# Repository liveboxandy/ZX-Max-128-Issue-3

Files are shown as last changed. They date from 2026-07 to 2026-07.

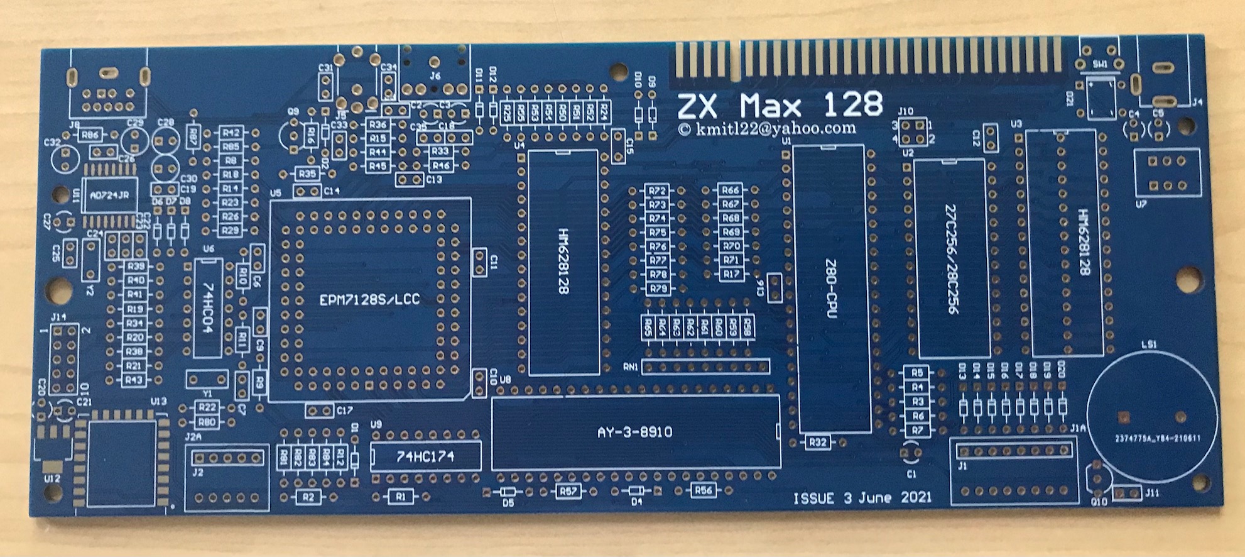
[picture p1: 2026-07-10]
ZX Max 128 Issue 3 June 2021 pcb .jpg

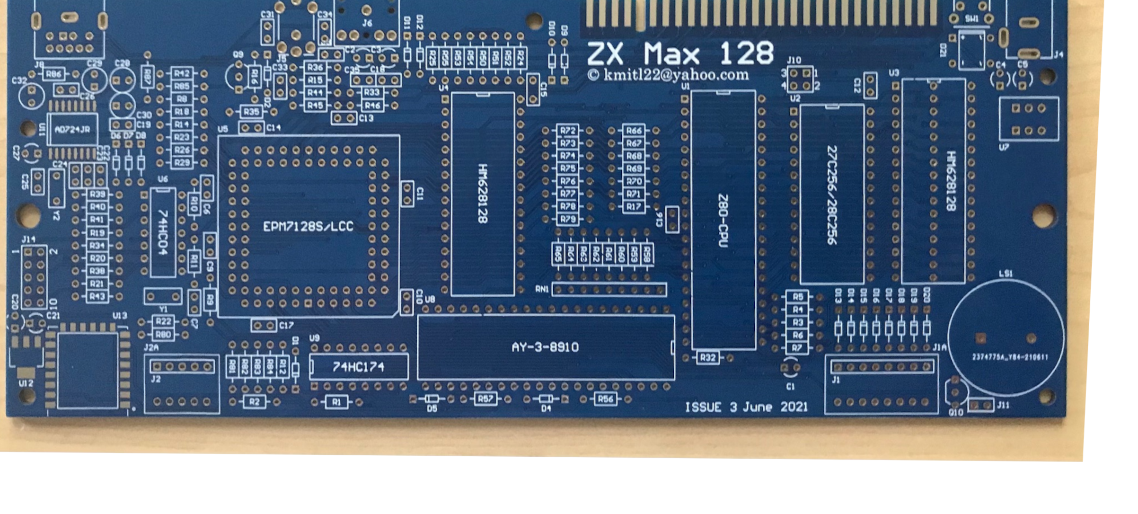
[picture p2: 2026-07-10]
Max 128 Issue 3 June 2021 pcb2.png

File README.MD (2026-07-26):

ZX Max 128 Issue 3.

This Kicad project has only been done so as to allow for a proper ibom that includes tracks and vias
to be created to make assembling easier.
A lot of work was done in order to ensure that the footprints were located as close as possible to 
those in the original as well tying to follow the existing track and via locations. Some of the
footprints that were downloaded from Digikey based on the parts in the official BOM do not fit 
exactly in their locations on the board. C15 is one example, I had to modify it's footprint to fit
the pad dimensions. Some other capacitors also do not fit correctly but appear to be close enough.

As such, although I have tried to be as accurate as possible I would NOT use these gerbers to have a
pcb manufactured without having another set of eyes checking that the schematic that I have produced
is correct to that produced by DonSuperfo and that the pcb data from Kicad reports no major errors 
with regards to copper tracing and via positions.

The KiCAD schematics 'should' be correct but nothing should be assumed as correct without checking with the original schematic and PCB layout. Although I have followed the original track and via layout further checking should be done before using these files to order a pcb with. Currently I would still order the pcb from PCBWay using the link from https://github.com/DonSuperfo/ZX-Max-128

Note that any part number for any device used in this project might not be the correct one from the original BOM as supplied from PCBWay as I had to change some parts to get a footprint that would fit in the space on the original pcb with the correct pin spacing. This required selecting a different part number or vendor. This applies mainly to capacitors. Some other parts are no longer available under that number from Digikey.

As always, measure twice and order one.

Use at your own risk.

For the jumpers/connectors on the board,

J1/J1A1 8 Way Keyboard Connector

J2/J2A1 5 Way Keyboard Connector

J3 Zx Expansion Connector

J4 DC Input can be any polarity. 

J5 Video is a TRRS, Tip-Video,RR-Left/Right, Screen-Ground.

J6 Ear/Mic. Wired as per ZX Spectrum 128K +3. TRS. Tip-Mic, Ring-Ear, Screen-Ground.

J7 Not Used

J8 SCART, mates with a Sega megadrive cable for SCART.

J9 Not Used

J10 EEPROM/EPROM selection, EEPROM 2-4/1-3, UVEPROM 2-1/4-3.

J11 Speaker On/Off

J12 Not Used

J13 Not Used

J14 JTAG for the EPM7128 wired as standard to an Altera device.

J15 Not Used

J16 Disable DivMMC, close = enable DivMMC, open = disable DivMMC or need to update program on U17

SW1 RESET

From information on the original website,

In order to make ACB output more balanced I would recommend following the -4.5 dB panning law rule and make these updates:

R54, R55 = 470 Ohm
R51, R52 = 560 Ohm
R50, R53 = 330 Ohm

The ratio of 560 / 330 = 1.6969 is a close approximation of 1 / 10^(-4.5 / 20) = 1.6788. 
Also the resulting equivalent resistance is around 1000 Ohm which leads to less distortion on AY outputs.

mismatch between the value on the scheme and in the BOM for part R32 (INT)
on scheme it is 470R but in BOM 10k.
it looks like in BOM incorrect value.

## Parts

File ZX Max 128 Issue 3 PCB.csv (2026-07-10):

Source: | E:\Kicad\ZX Max 128 Issue 3\ZX Max 128 Issue 3 PCB.kicad_sch
Date: | 2026-07-10T22:37:54
Tool: | Eeschema 10.0.4
Generator: | C:\Program Files\KiCad\7.0\bin\scripting\plugins/bom_csv_grouped_by_value_with_fp.py
Component Count: | 164
Ref | Qnty | Value | Cmp name | Footprint | Description | Vendor | DNP
C1, C2, C3, C4, C20, C21, C27 | 7 | 10uF 25V | ECA-1EM100B | Mod:CAPPRD200W50D500H1100 | ECA-1EM100B - 10uF Aluminum Electrolytic Capacitors Radial
C5 | 1 | 22uF 16V | ECA-1EM100B | Mod:CAPPRD200W50D500H1100 | ECA-1EM100B - 10uF Aluminum Electrolytic Capacitors Radial
C6, C7 | 2 | 27pF | FG18C0G1H270JNT06 | Mod:CAPRB250W50L400T250H550
C8, C9, C10, C11, C12, C13, C14, C16, C17, C18, C22, C23, C24, C26, C31, C34 | 16 | 100nF | K104Z15Y5VF5TL2 | Mod:CAPRB250W50L400T250H550 | Vishay K 100nF Ceramic Multilayer Capacitor, 100 V dc, +85C, Y5V Dielectric, +80 %, -20 %
C15 | 1 | 100nF | K104Z15Y5VF5TL2 | Mod:Capacitor 3.8mm PItch | Vishay K 100nF Ceramic Multilayer Capacitor, 100 V dc, +85C, Y5V Dielectric, +80 %, -20 %
C19, C35 | 2 | 3n3 50V | K104Z15Y5VF5TL2 | Mod:CAPRB250W50L400T250H550 | Vishay K 100nF Ceramic Multilayer Capacitor, 100 V dc, +85C, Y5V Dielectric, +80 %, -20 %
C25 | 1 | 10pF | K104Z15Y5VF5TL2 | Mod:CAPRB250W50L400T250H550 | Vishay K 100nF Ceramic Multilayer Capacitor, 100 V dc, +85C, Y5V Dielectric, +80 %, -20 %
C28, C29, C30, C32 | 4 | 220uF 16V | 16YXJ220MT16.3X11 | Mod:CAP_YX_6P3X11_RUB
C33 | 1 | 10nF 50V | K104Z15Y5VF5TL2 | Mod:CAPRB250W50L400T250H550 | Vishay K 100nF Ceramic Multilayer Capacitor, 100 V dc, +85C, Y5V Dielectric, +80 %, -20 %
D1, D2, D4, D5, D6, D7, D8, D9, D10, D11, D12, D13, D14, D15, D16, D17, D18, D19, D20 | 19 | 1N4148 | 1N4148 | Mod:DIOAD753W49L380D172B | Diode 1N4148
D21 | 1 | DF02M | DF02M | Mod:DIP825W58P510L832H543Q4N | Bridge Rectifier DF02M 1A
J1 | 1 | 8 Pin FFC | 5-520315-8 | Mod:55203155 | Connector FFC Socket 8 Pin
J1A1 | 1 | 8 Pin JST XH | B8B-XH-A_LF__SN_ | Mod:JST_B8B-XH-A_LF__SN_ | Connector Header Through Hole 8 position 0.098 (2.50mm)
J2 | 1 | 5 Pin FFC | 5-520315-5 | Mod:55203155 | Connector FFC Socket 5 Pin
J2A1 | 1 | 5 Pin JST XH | B5B-XH-A_LF__SN_ | Mod:JST_B5B-XH-A_LF__SN_ | Connector Header Through Hole 5 position 0.098 (2.50mm)
J3 | 1 | ZX_48K_EDGE | ZX_48K_EDGE | Mod:ZX_BUS_B_TOP | ZX Spectrum 48K Edge Connector
J4 | 1 | PJ-002A | PJ-002A | Mod:CUI_PJ-002A
J5 | 1 | AV Jack | AudioJack3 | Mod:PJ-322A | AV Jack PJ-322
J6 | 1 | Connector Audio 3525N | SJ1-3525N | Mod:CUI_SJ1-3525N | Connector Audio 3525N
J8 | 1 | Connector 9 Pin Mini DIN | KMDGX-9S-BS-1 | Mod:KMDGX9SBS1 | Connector 9 Pin MiniDin
J10 | 1 | Conn_02x02_Odd_Even | Conn_02x02_Odd_Even | Connector_PinHeader_2.54mm:PinHeader_2x02_P2.54mm_Vertical | Generic connector, double row, 02x02, odd/even pin numbering scheme (row 1 odd numbers, row 2 even numbers), script generated (kicad-library-utils/schlib/autogen/connector/)
J11 | 1 | CON2 | M20-9990246 | Mod:HARWIN_M20-9990246 | Header 2x1
J14 | 1 | Header 5x2 | 10129381-910002BLF | Mod:AMPHENOL_10129381-910002BLF | Header 5x2
LS1 | 1 | Speaker | Speaker | Mod:Speaker | Speaker
Q9, Q10 | 2 | Transistor BC548 | BC548BTA | Mod:BC548BTA
R1, R2, R7, R9, R12, R32, R36, R56, R57, R58, R59, R60, R61, R62, R63, R64, R65, R66, R67, R68, R69, R70, R71, R72, R73, R74, R75, R76, R77, R78, R79 | 31 | 470R | CF14JT470R | Mod:STA_CF14_STP | 470R
R3, R4, R5, R6, R15, R16, R24, R25, R35, R45, R80, R81, R82, R83, R84 | 15 | 10K0 | CF14JT10K0 | Mod:STA_CF14_STP | Resistor 10K0
R8 | 1 | 2K70 | CF14JT2K70 | Mod:STA_CF14_STP | 2K70
R10 | 1 | 1M00 | CF14JT1M00 | Mod:STA_CF14_STP | 1M00
R11, R50, R53, R54, R55 | 5 | 1K00 | CF14JT1K00 | Mod:STA_CF14_STP | 1K00
R14, R18, R23, R26, R29 | 5 | 68R0 | CF14JT68R0 | Mod:STA_CF14_STP | 68R0
R17, R22 | 2 | 4K7 | CF14JT4K70 | Mod:STA_CF14_STP | 4K70
R19, R20, R21, R34, R38, R43 | 6 | 150R | CF14JT150R | Mod:STA_CF14_STP | 150R
R33 | 1 | 33K0 | CF14JT33K0 | Mod:STA_CF14_STP | 33K0
R39, R40, R41, R42, R86, R87 | 6 | 75R0 | CF14JT75R0 | Mod:STA_CF14_STP | 75R0
R44, R46 | 2 | 150K | CF14JT150K | Mod:STA_CF14_STP | 150K
R51, R52 | 2 | 2K20 | CF14JT2K20 | Mod:STA_CF14_STP | 2K20
R85 | 1 | 470K | CF14JT470K | Mod:STA_CF14_STP | 470K
RN1 | 1 | 10K | 4609X-101-103LF | Mod:SIP249W50P254L2281H508Q9
SW1 | 1 | Switch 6x6 RA | 2-1825027-0 | Mod:SW2_1825027-G_TEC
U1 | 1 | Z80 | Z84C0010PEG | Mod:Z80_Socket | Z80 CPU
U2 | 1 | EEPROM/EPROM 32Kx8 | AT27C256R-45PU | Mod:DIP1556W56P254L3702H483Q28N | EEPROM/EPROM 32Kx8
U3 | 1 | AS6C1008-55PCN | AS6C1008-55PCN | Mod:U3
U4 | 1 | AS6C1008-55PCN | AS6C1008-55PCN | Mod:PDIP-32_MIL600_ALL
U5 | 1 | EPM7128SLC | PLCC-84-AT | Mod:PLCC84AT | EPM7128SLC-84 PLCC Socket
U6 | 1 | 74HC04 | 74HC04_1 | Mod:DIP794W53P254L1930H508Q14N | Hex Inverter
U7 | 1 | R-78E5.0-1.0 | R-78E5.0-1.0 | Mod:CONV_R-78E5.0-1.0
U8 | 1 | AY-3-8910 | AY-3-8910 | Mod:Z80_Socket
U9 | 1 | SN74HC174N | SN74HC174N | Mod:DIP794W53P254L1930H508Q16N | Hex D flip-flop w/reset,SN74HC174N DIP16
U11 | 1 | AD724JRZ | AD724JRZ | Mod:RW_16_ADI | RGB - PAL Encoder
U12 | 1 | 3V3 1Amp | AZ1117IH-3.3TRG1 | Mod:SOT230P700X185-4N | Voltage Regulator 3V3 1Amp
U15 | 1 | ESP8266-12E | ESP8266-12E | Mod:WIFI_Module_ESP8266_12E | ESP8266-12E Bluetooth Module
Y1 | 1 | 28.375Mhz | Crystal | Mod:Crystal_HC49-4H_Vertical | Two pin crystal
Y2 | 1 | 4.433Mhz | Crystal | Mod:Crystal_HC49-4H_Vertical | Two pin crystal

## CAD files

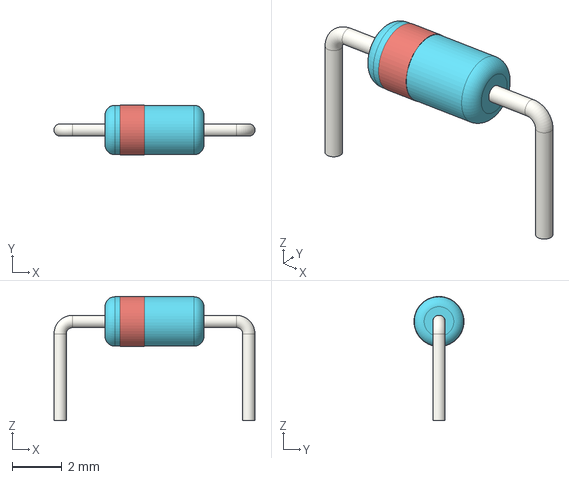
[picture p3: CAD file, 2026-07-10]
Step/D_DO-35_SOD27_P7.62mm_Horizontal.step
8.12 x 2.02 x 5.01 mm

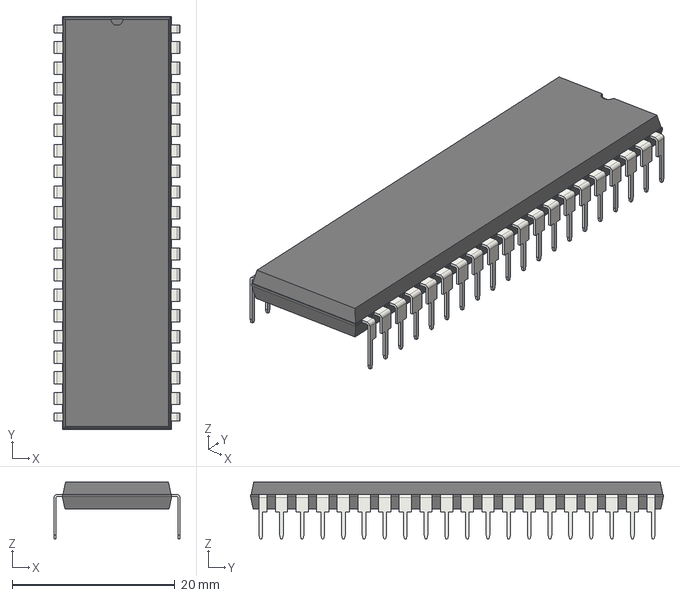
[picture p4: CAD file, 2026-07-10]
Step/DIP-40_W15.24mm.step
15.5 x 50.8 x 6.98 mm

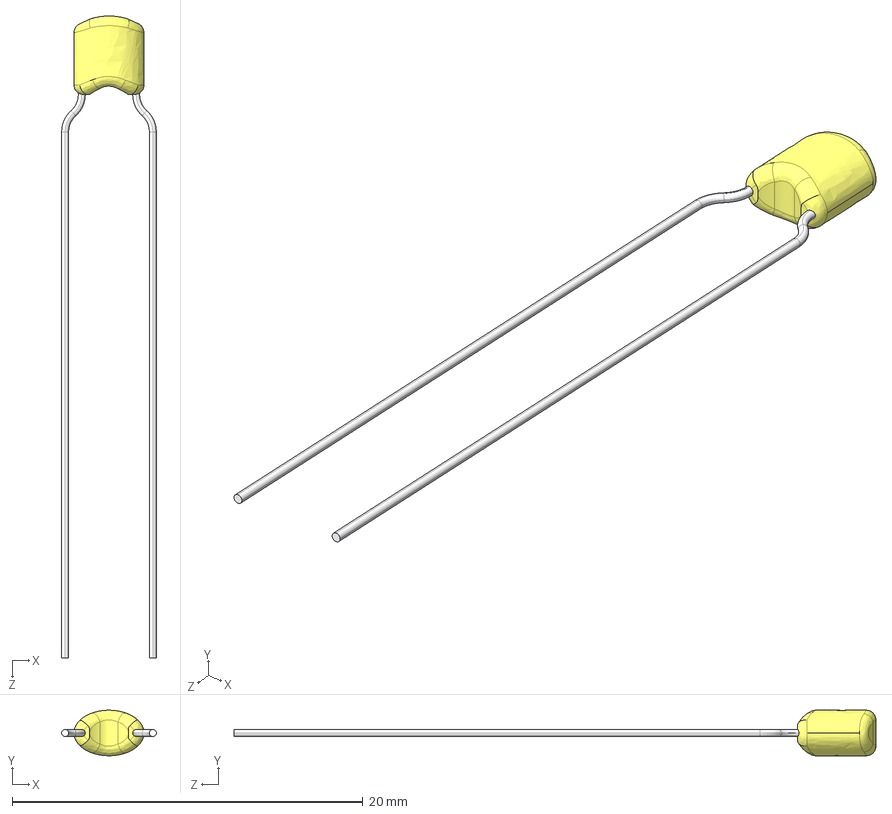
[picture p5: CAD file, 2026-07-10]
Step/Capacitor 100nF 50V MLCC K104Z15Y5VF5TL2.stp
5.40 x 2.60 x 36.6 mm

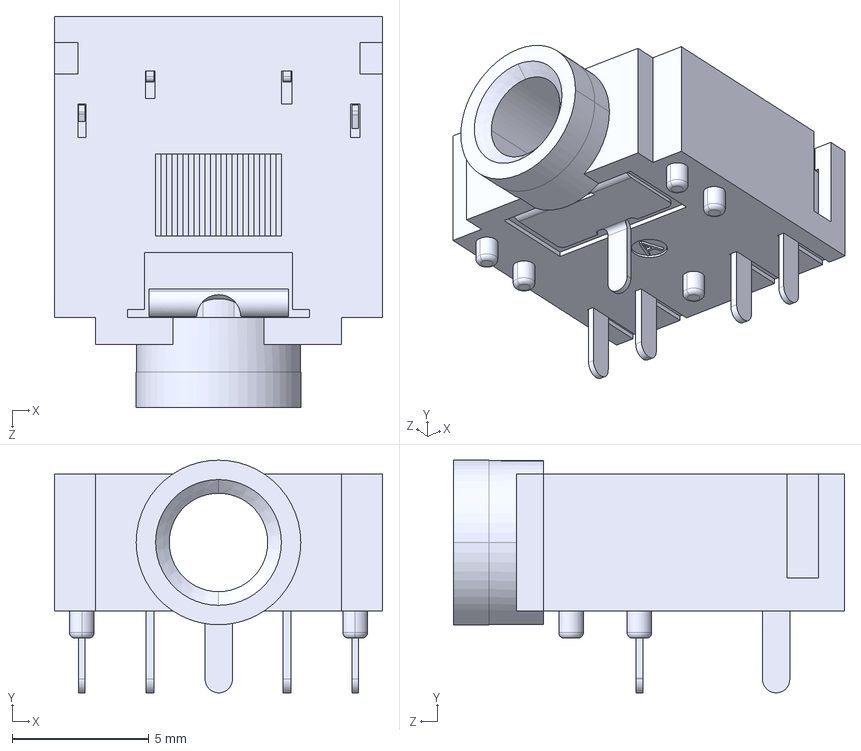
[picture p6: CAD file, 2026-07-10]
Step/Audio Connector SJ1-3525N.step
12.0 x 8.51 x 14.3 mm

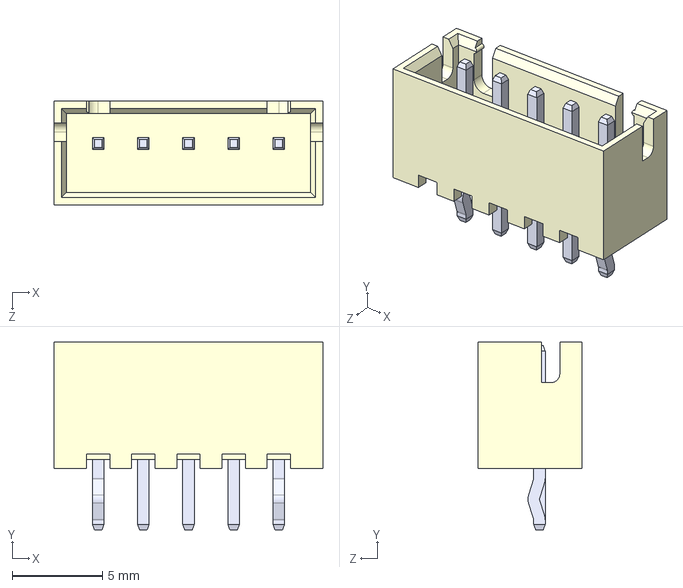
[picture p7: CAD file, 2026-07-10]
Step/B5B-XH-A_LF__SN_.step
14.9 x 10.4 x 5.75 mm

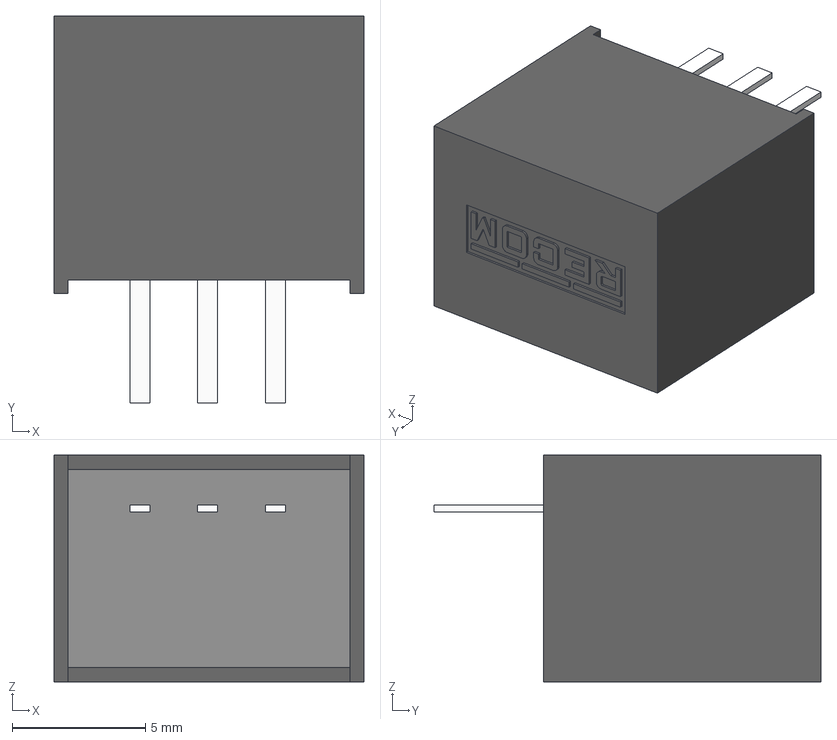
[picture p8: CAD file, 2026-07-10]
Step/R-78E5.0-1.0.step
11.6 x 14.5 x 8.50 mm

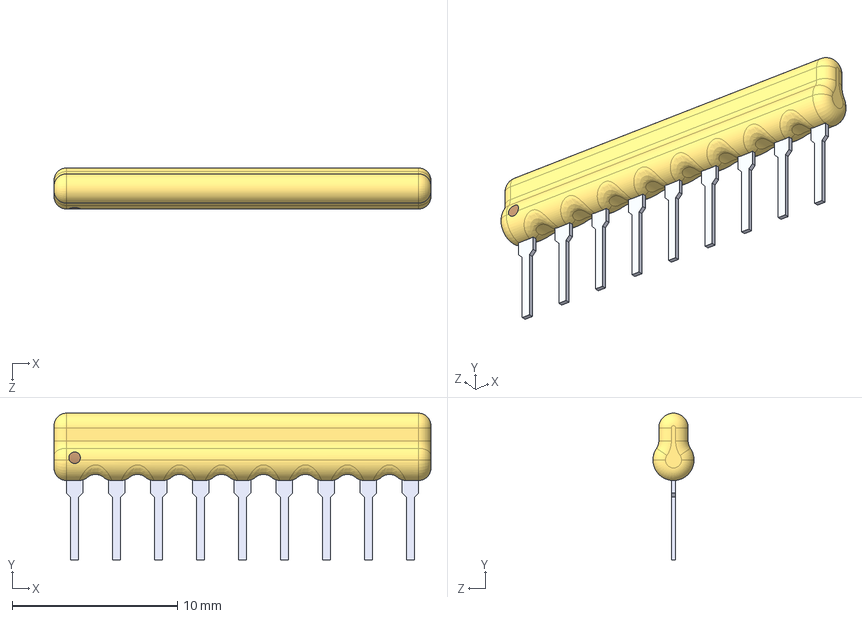
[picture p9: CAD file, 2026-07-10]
Step/RNET 10K 9PIn 4609X-101-103LF.step
22.8 x 8.88 x 2.49 mm

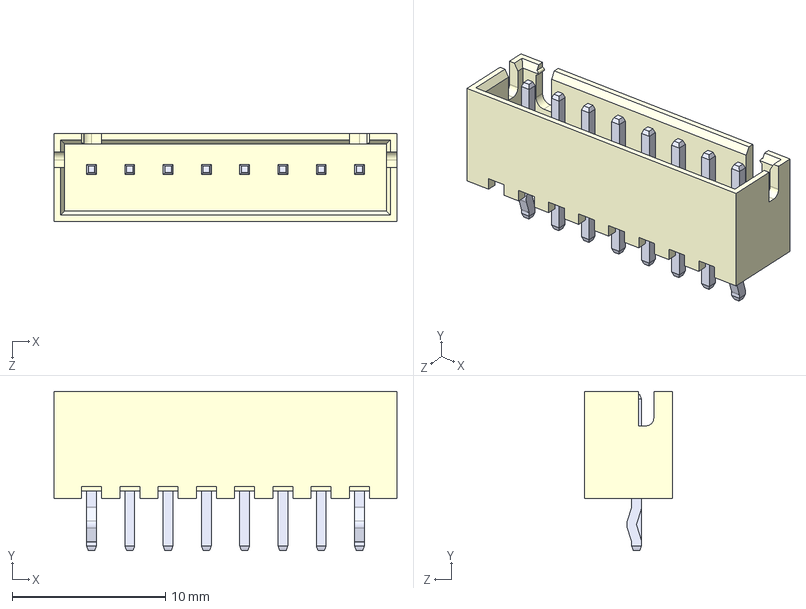
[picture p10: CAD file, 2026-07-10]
Step/B8B-XH-A_LF__SN_.step
22.4 x 10.4 x 5.75 mm

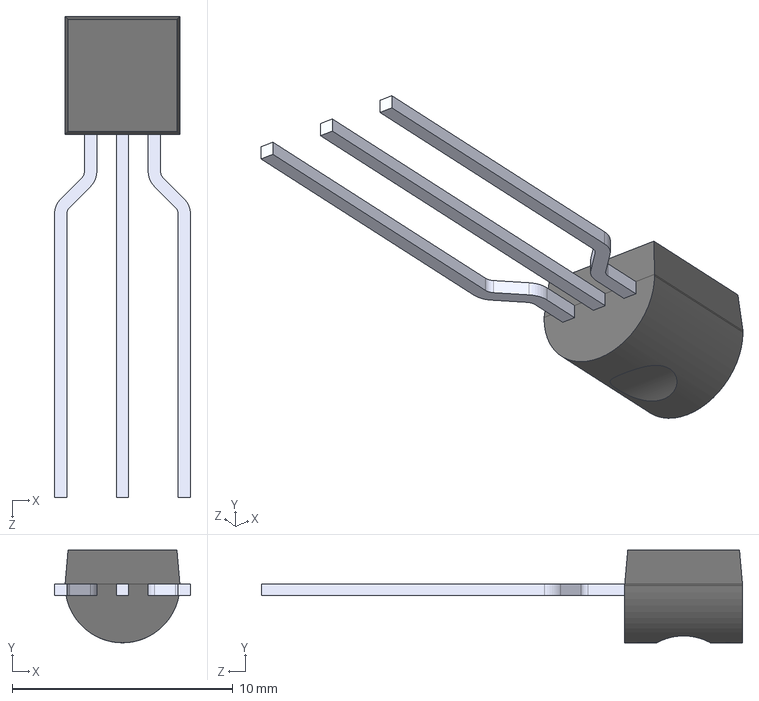
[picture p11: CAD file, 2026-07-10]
Step/Transistor BC548BTA.stp
6.16 x 4.19 x 21.8 mm

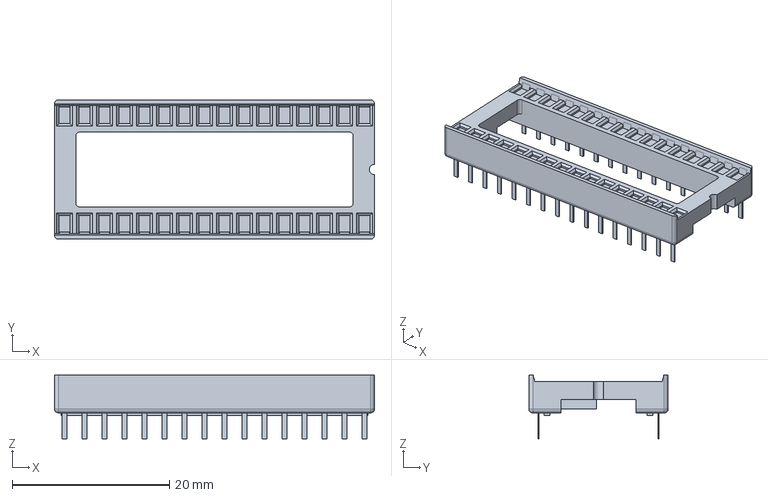
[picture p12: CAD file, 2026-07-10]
Step/DIP-32_W15.24mm_Socket-1.stp
40.6 x 17.7 x 8.10 mm

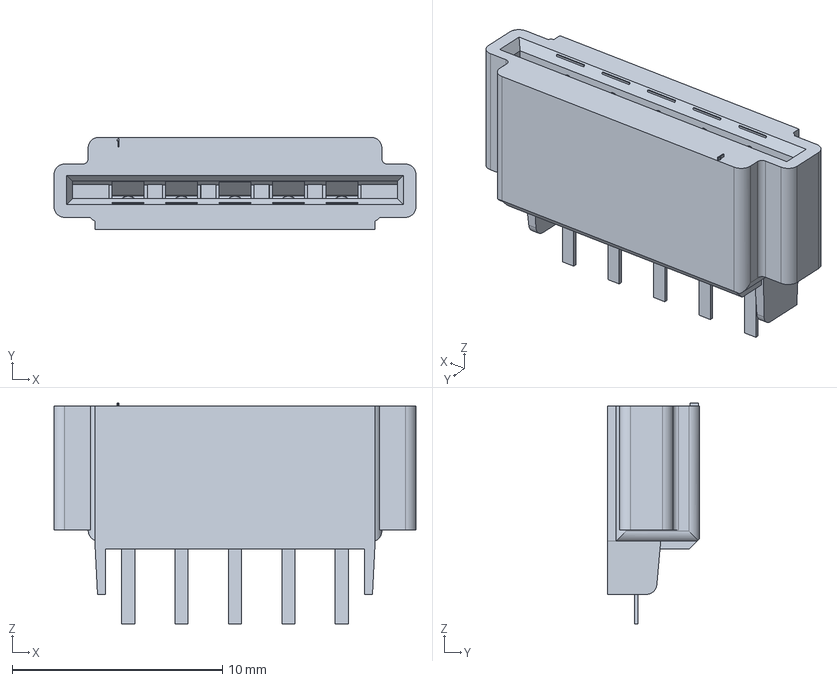
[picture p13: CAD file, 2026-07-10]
Step/Connector 5 Way Keyboard CONN_5-520315-5.stp
17.2 x 4.39 x 10.5 mm

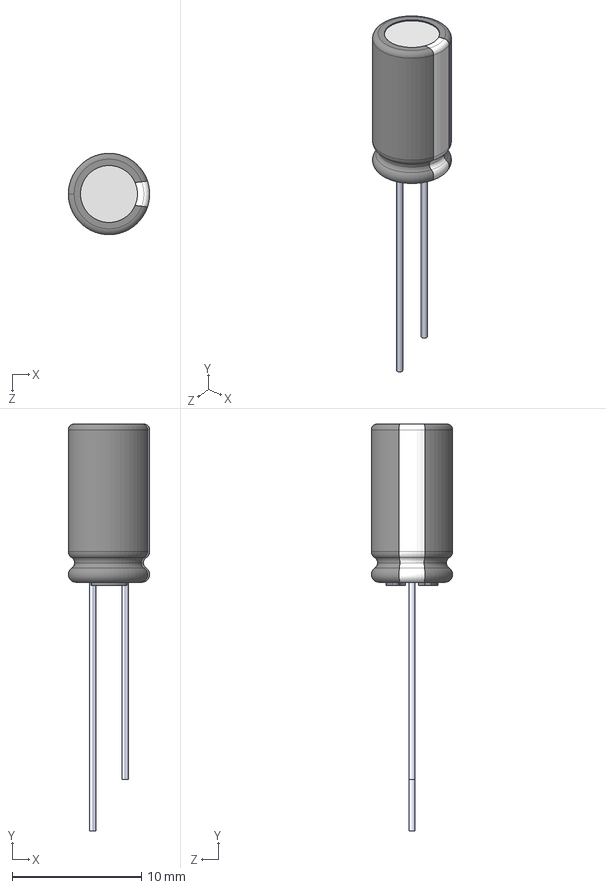
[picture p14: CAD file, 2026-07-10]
Step/16YXJ220MT16.3X11.step
6.30 x 31.5 x 6.30 mm

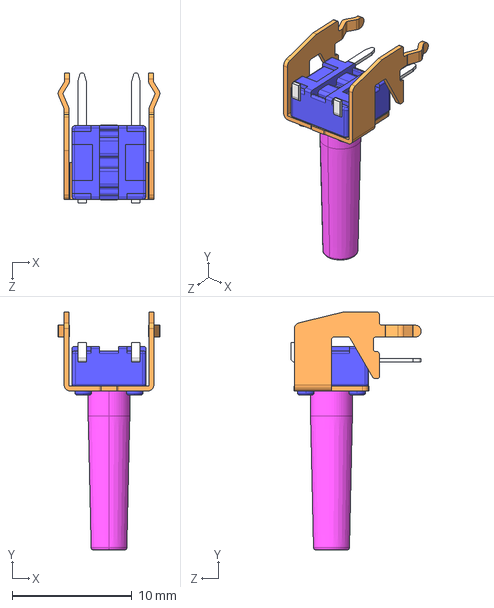
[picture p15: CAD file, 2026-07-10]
Step/Switch 6mm RA SKHHNHA010.stp
8.50 x 19.9 x 10.9 mm

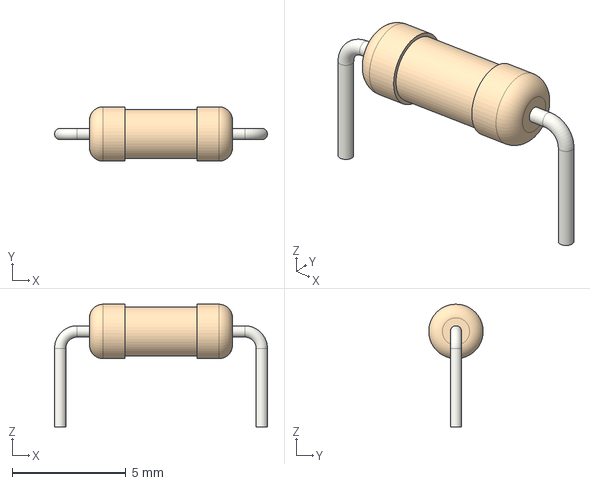
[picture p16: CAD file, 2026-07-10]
Step/Resistor.08.88.step
9.38 x 2.40 x 5.40 mm

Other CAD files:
Step/CONN_5-520315-8_TYC.stp
Step/ESP8266-12E_ESP-12E.step
Step/DIP-16_W7.62mm_Socket.step
Step/DIP-14_W7.62mm_Socket.step
Step/10129381-910002BLF.step
Step/9Pin MiniDIN KMDGX-9S-BS-1.stp
Step/9Pin MiniDIN KMDGX-9S-BS-1_A1.IGS
Step/ADI724JRZ RW_16_ADI.step
Step/AS6C6264-55PCN.stp
Step/AT27C256R-45PU.stp
Step/Capacitor 100pF 50V MLCC K101J15C0GF53L2.stp
Step/Capacitor 10nF 100V MLCC FA18C0G2A103JRU06.step
Step/Capacitor 10uF 25V ECA-1EM100B.stp
Step/Capacitor 22uF 16V 5x7 EEAGA1C220H.step
Step/Connector 8 Way Keyboard CONN_5-520315-8_TYC.stp
Step/Connector Pin-Pin 1x2 M20-9990246.step
Step/DF02M.stp
Step/DIP-14_W7.62mm.step
Step/DIP-16_W7.62mm.step
Step/DIP-28_W15.24mm.step
Step/DIP-28_W15.24mm_Socket.step
Step/DIP-32_W15.24mm.step
Step/DIP-32_W15.24mm_Socket.step
Step/DIP-40_W15.24mm_Socket.step
Step/Header 5x2 Pin-Pin 10129381-906002BLF.step
Step/PJ-002A.step
Step/PJ-322.step
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

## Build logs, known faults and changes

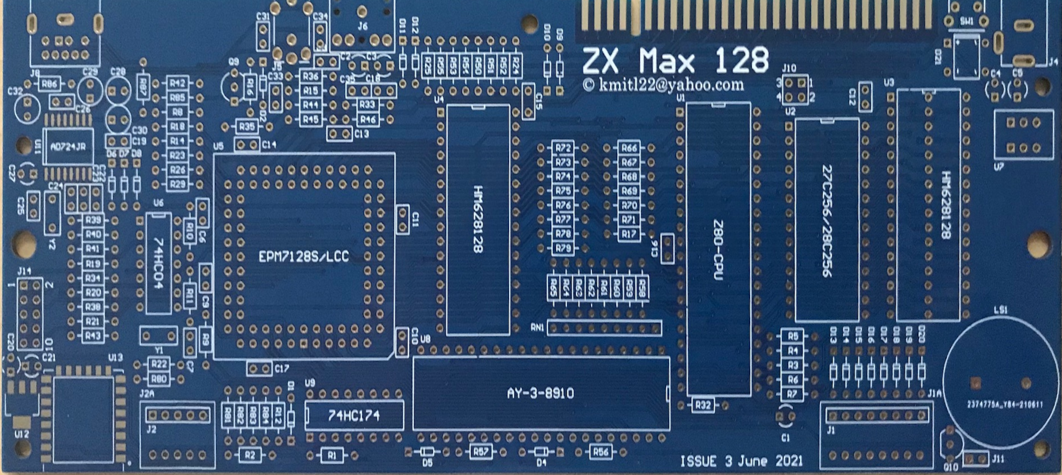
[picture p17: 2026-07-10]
Max 128 Issue 3 June 2021 pcb.png

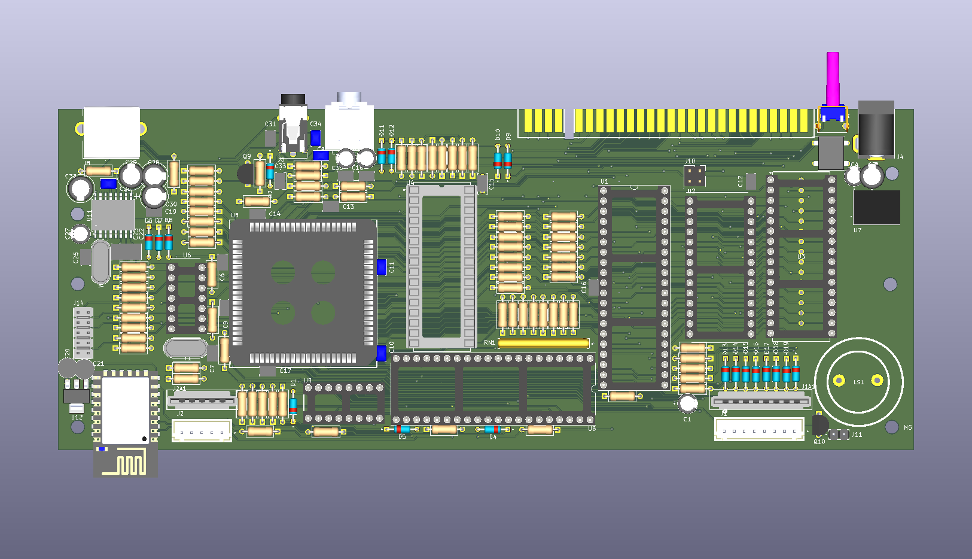
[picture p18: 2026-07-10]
ZX Max 128 Issue 3 PCB.png

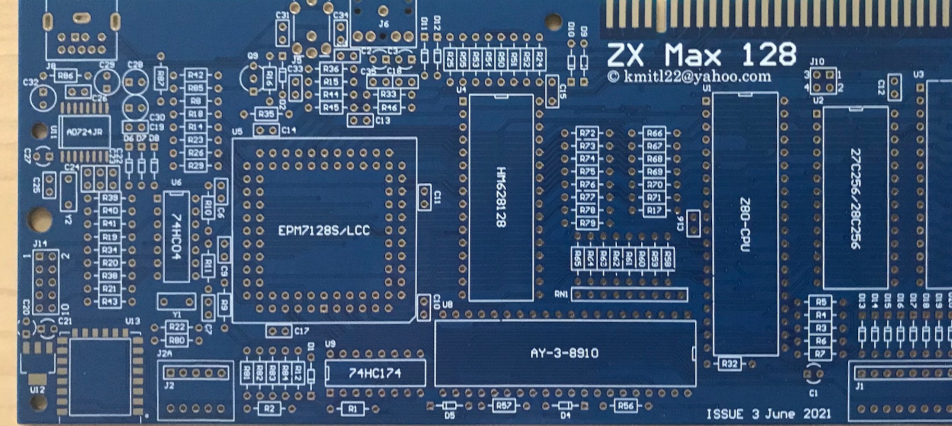
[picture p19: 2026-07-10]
Max 128 Issue 3 June 2021 pcb1.png

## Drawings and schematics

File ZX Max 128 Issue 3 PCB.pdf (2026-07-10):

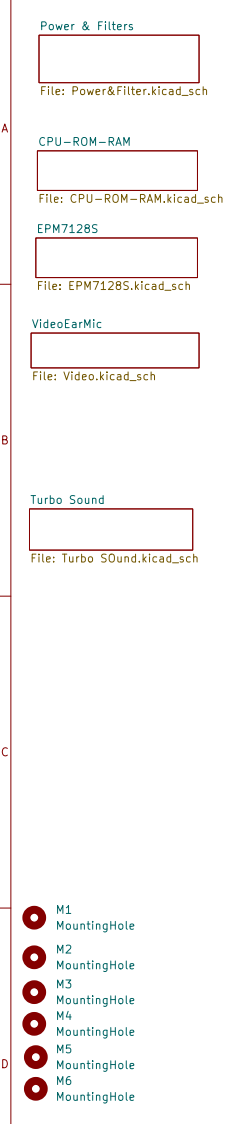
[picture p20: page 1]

Power & Filters File: Power&Filter.kicad_sch CPU-ROM-RAM
File: EPM7128S.kicad_sch M3 MountingHole M6 MountingHole M4 MountingHole M2 MountingHole M5 MountingHole M1 MountingHole

File: CPU-ROM-RAM.kicad_sch

Sheet: /
File: ZX Max 128 Issue 3 PCB.kicad_sch
Title:

Size: A4 | Rev:
KiCad E.D.A. 10.0.4 | Id: 1/6

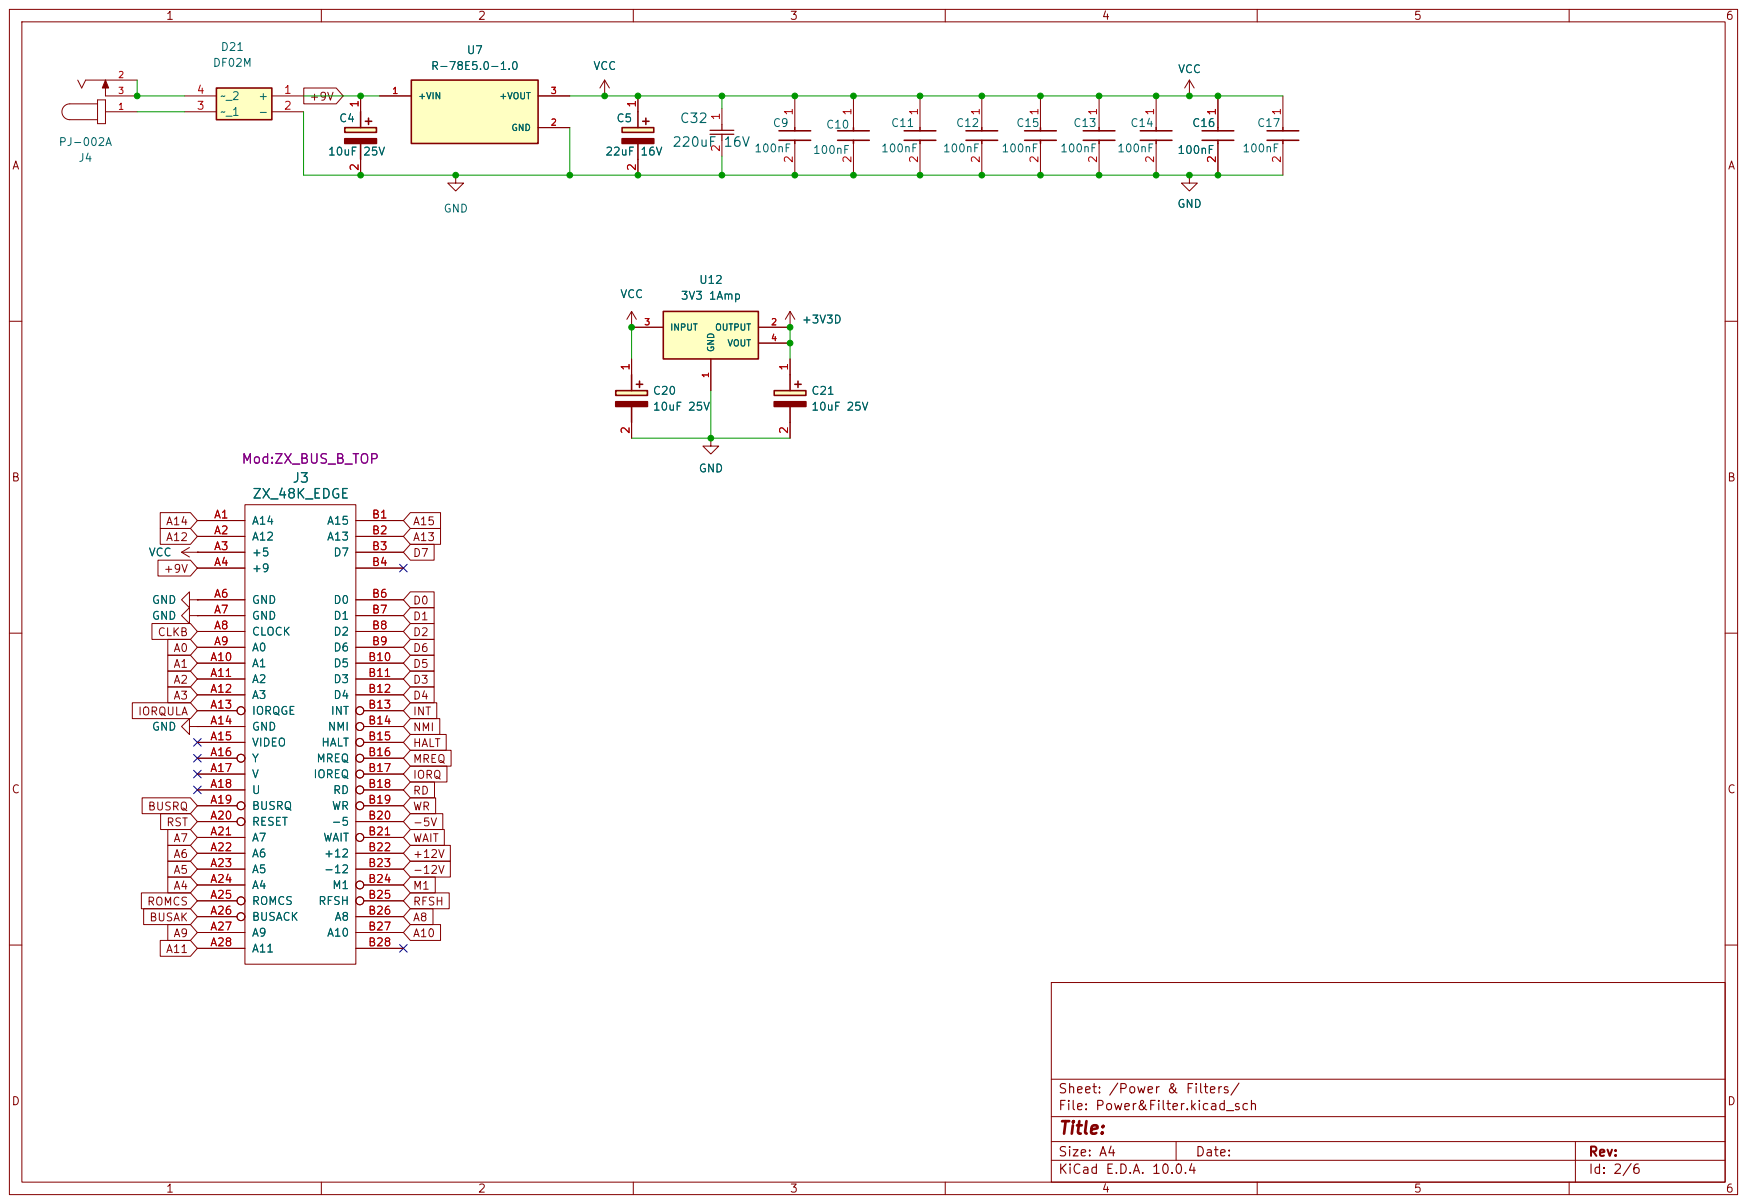
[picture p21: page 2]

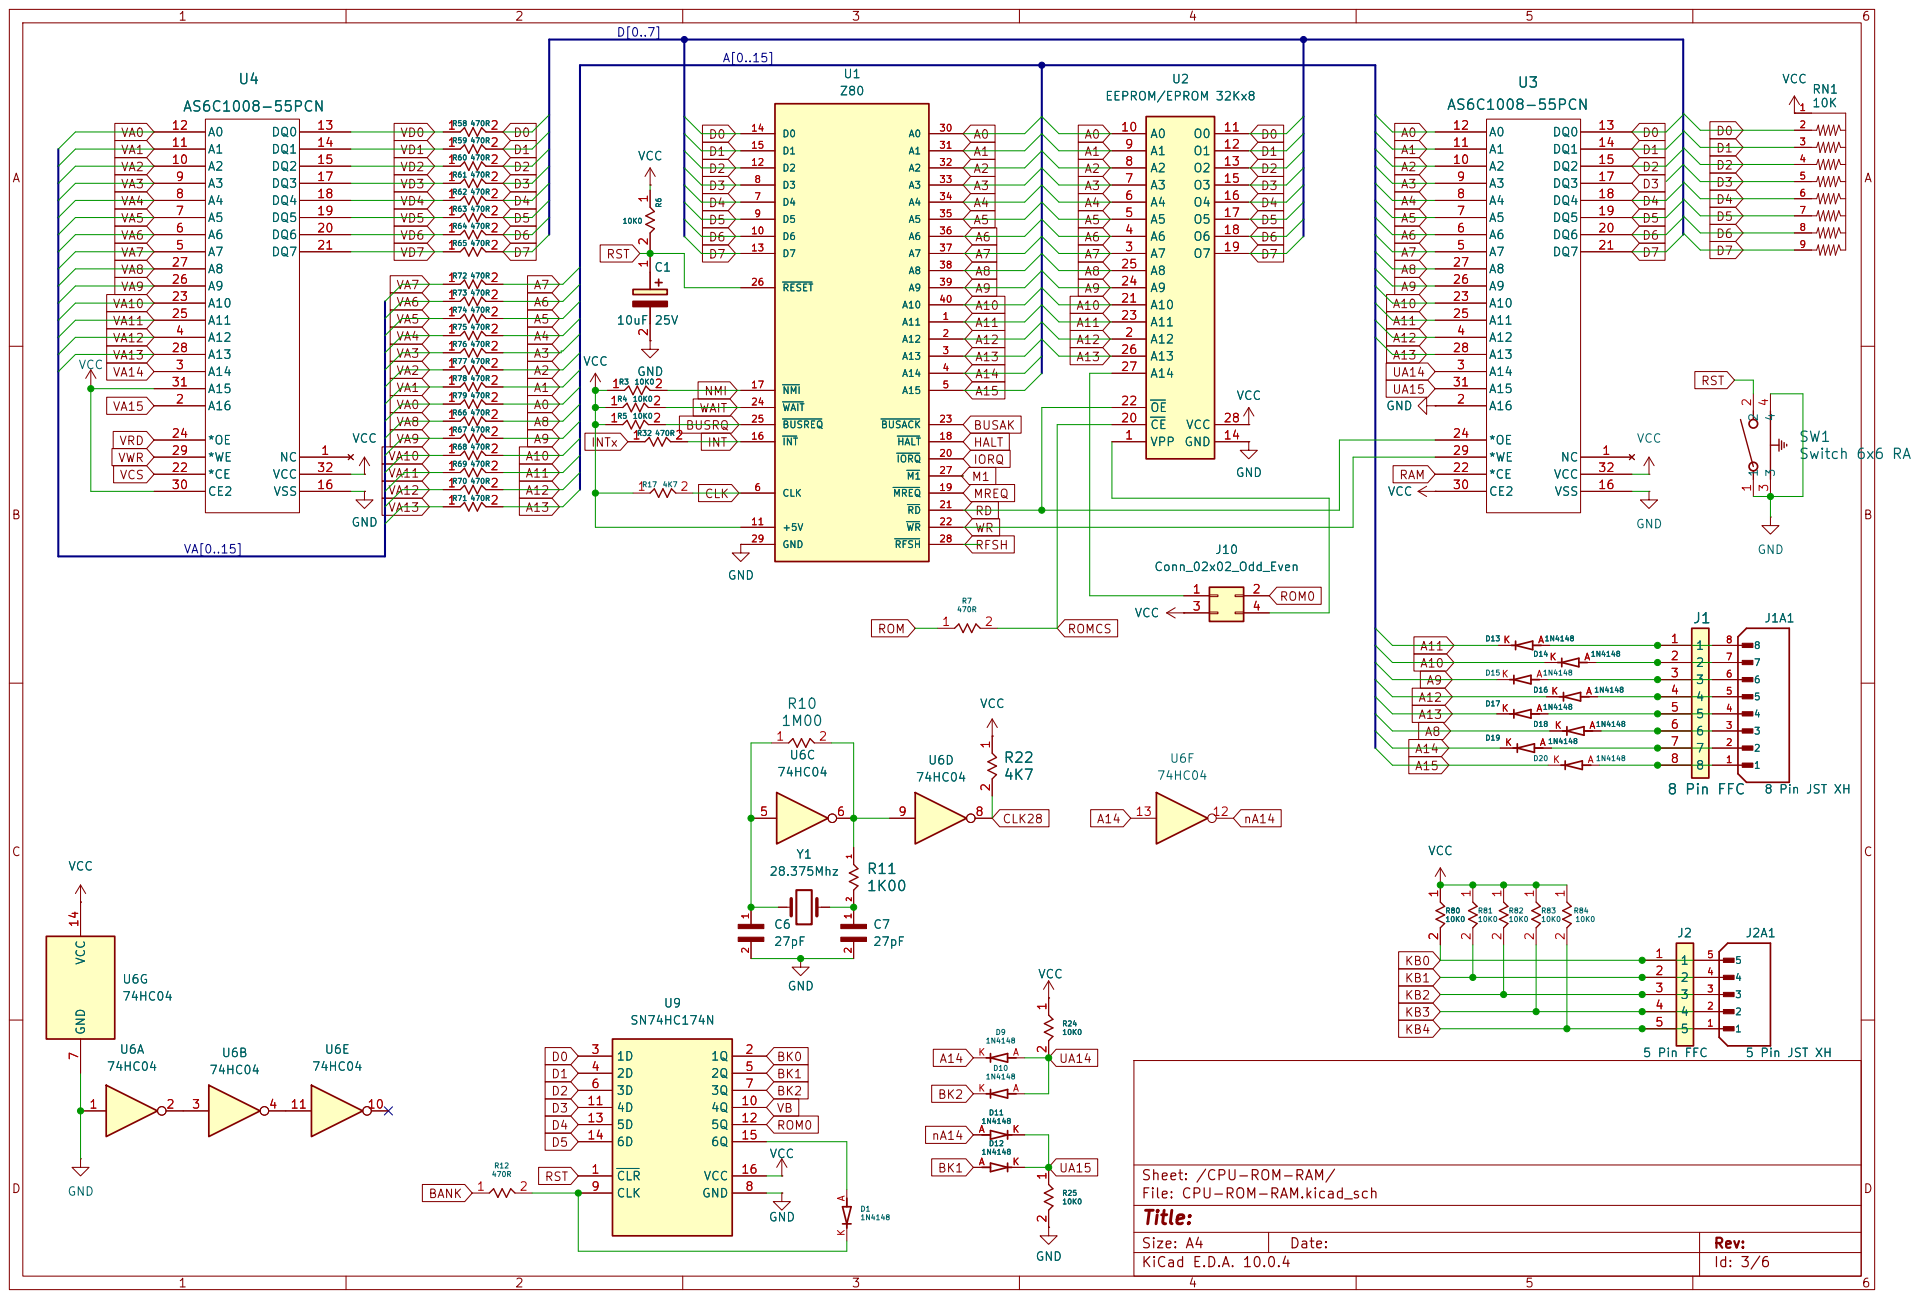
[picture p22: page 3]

Z80 | EEPROM/EPROM 32Kx8

Sheet: /CPU-ROM-RAM/
File: CPU-ROM-RAM.kicad_sch
Title:

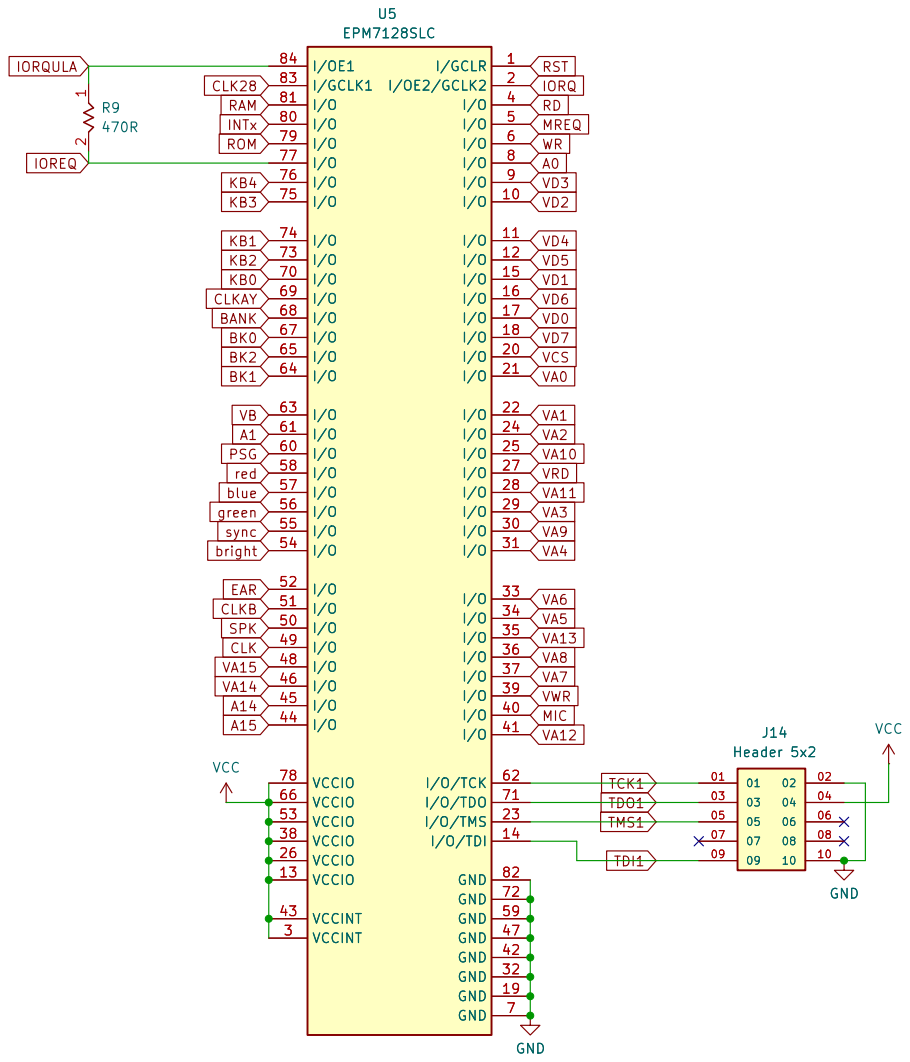
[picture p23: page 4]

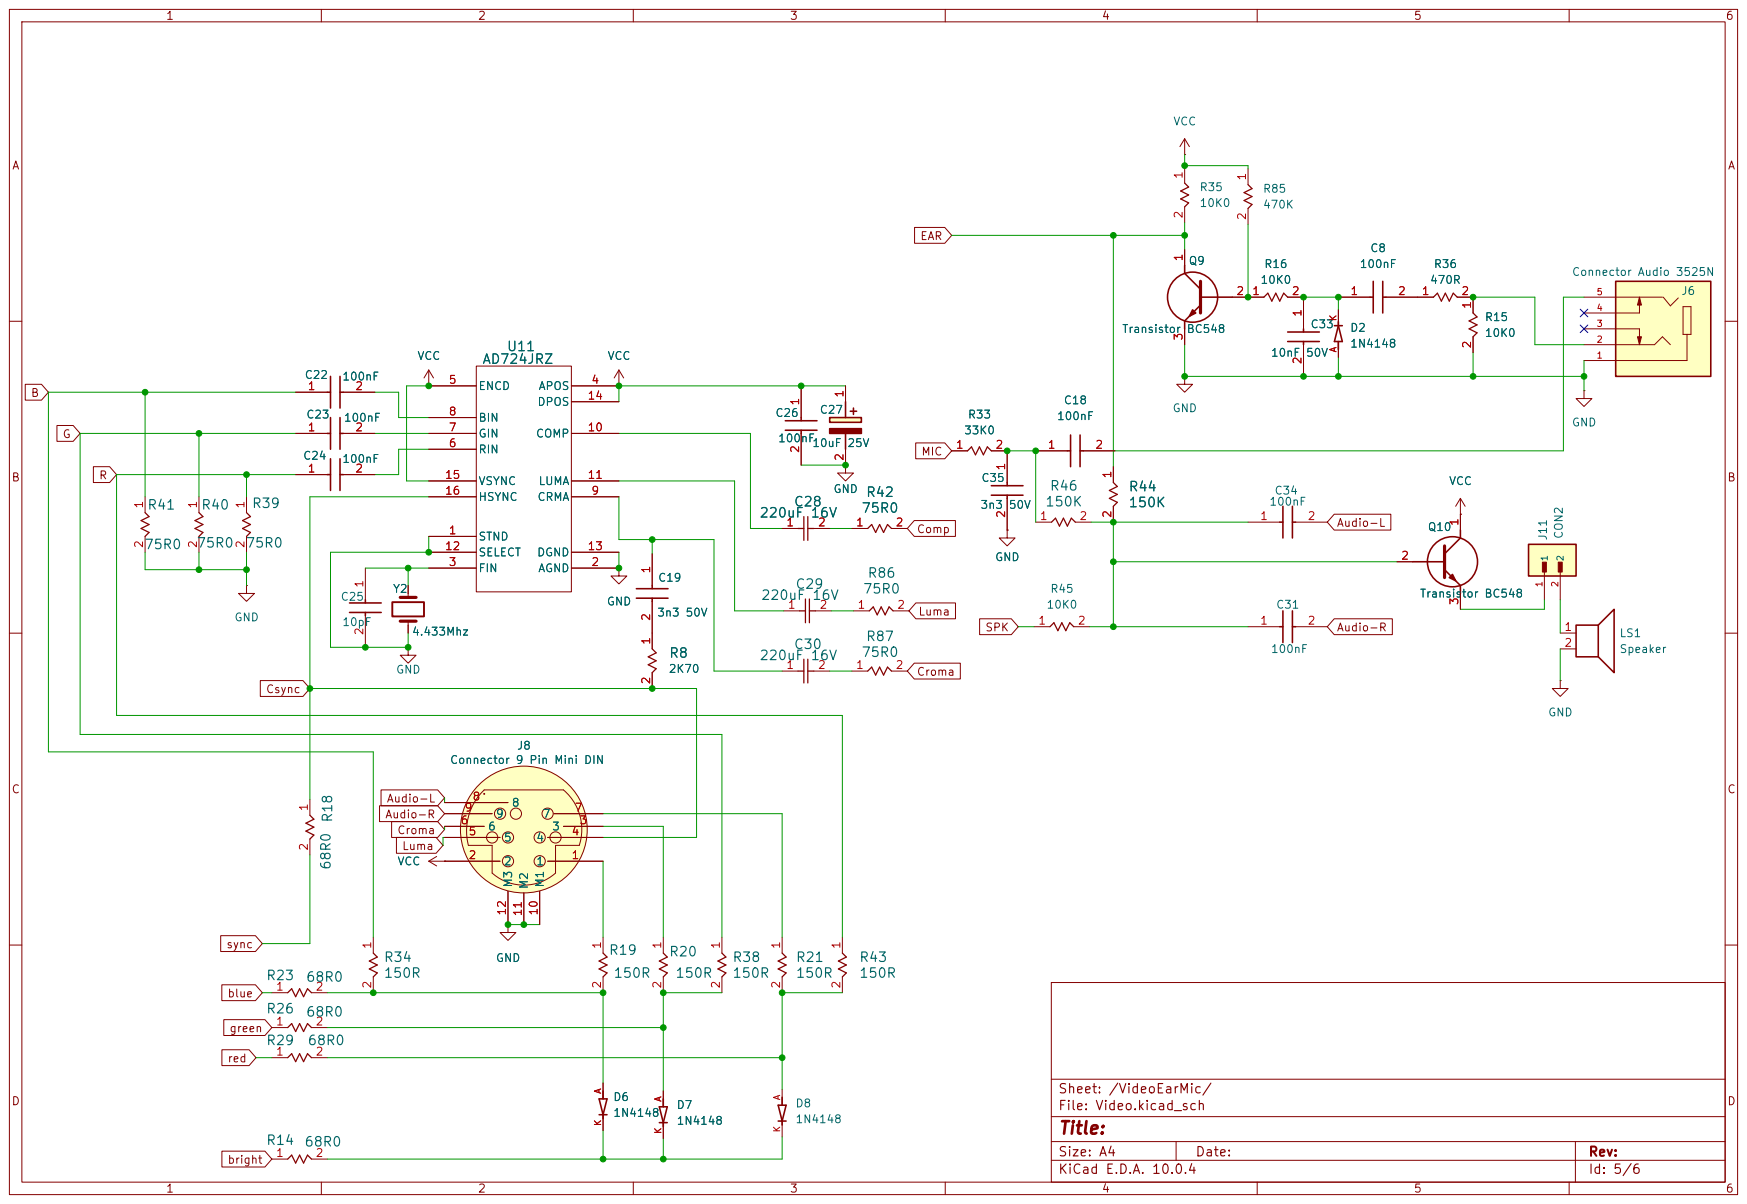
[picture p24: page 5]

J8 Connector 9 Pin Mini DIN

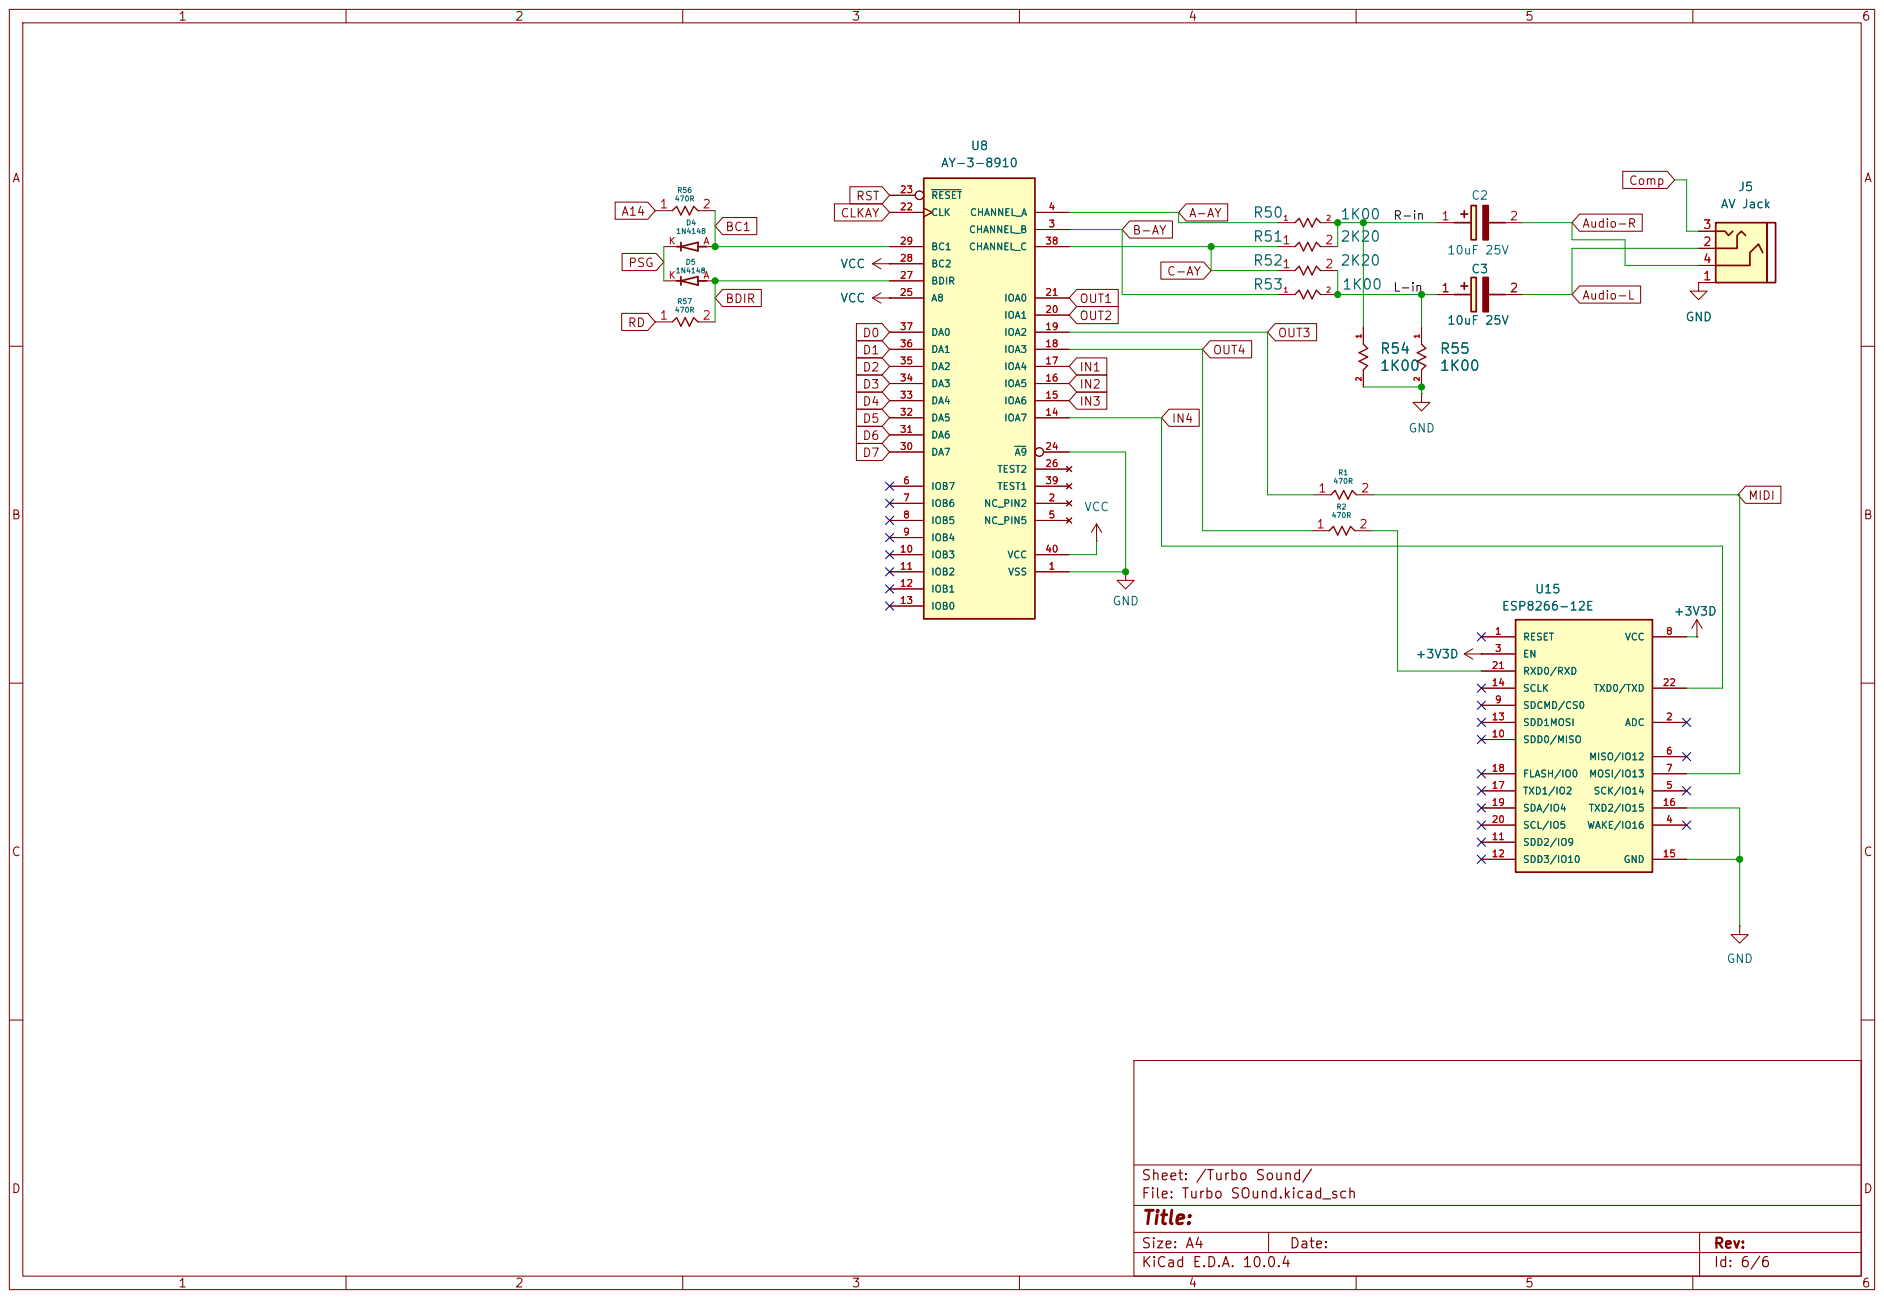
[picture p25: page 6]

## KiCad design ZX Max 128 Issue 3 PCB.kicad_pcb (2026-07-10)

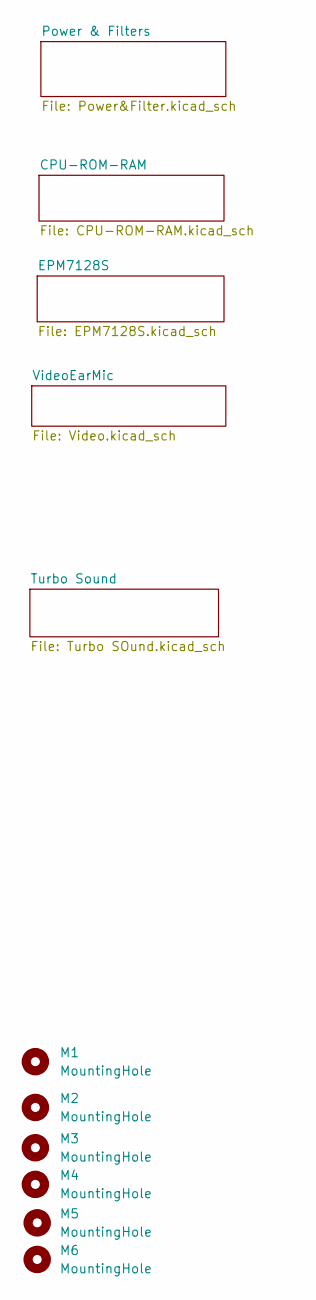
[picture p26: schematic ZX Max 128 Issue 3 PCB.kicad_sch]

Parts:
M1, M2, M3, M4, M5, M6: MountingHole; MountingHole_3.2mm_M3_DIN965

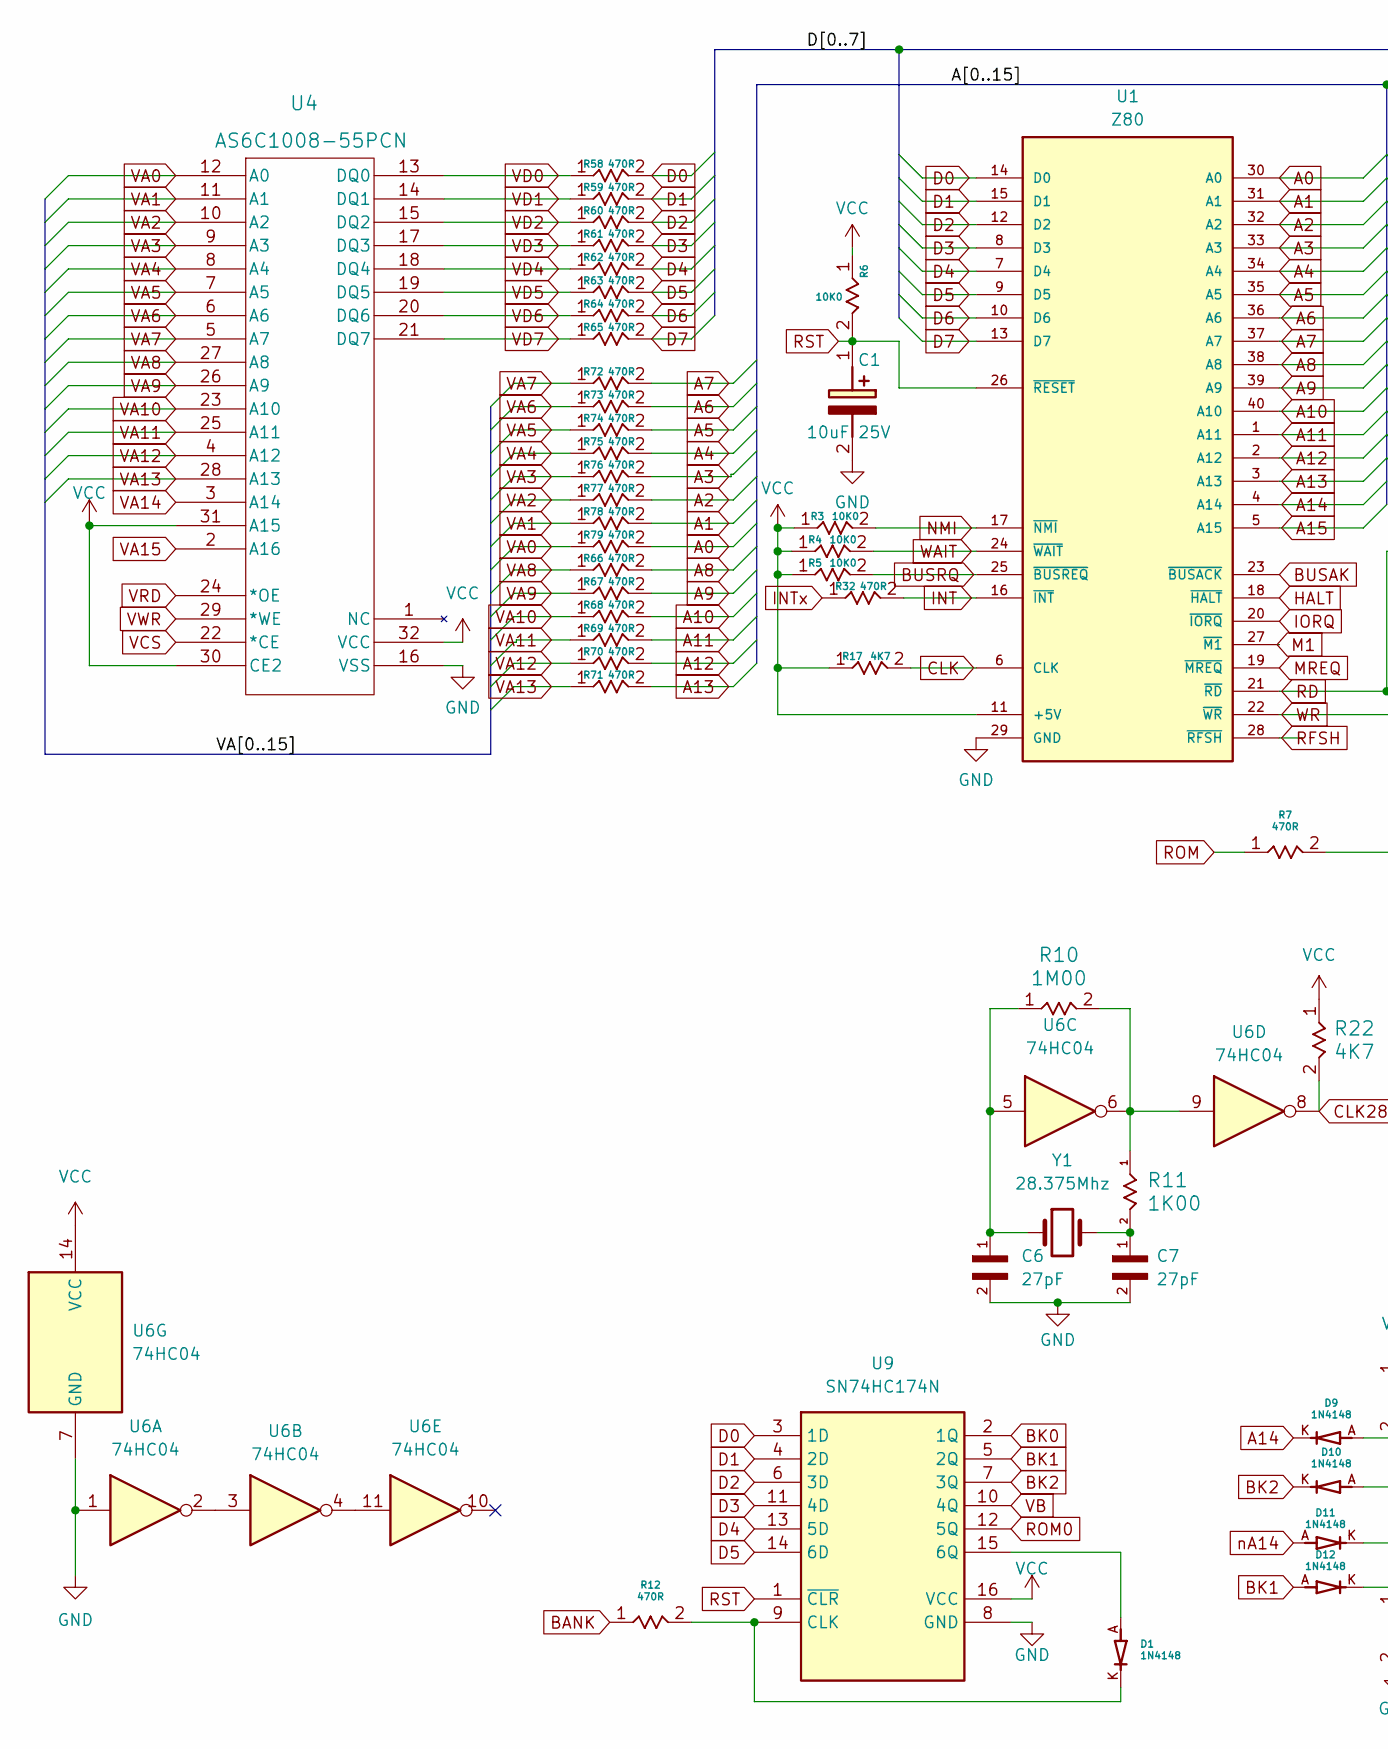
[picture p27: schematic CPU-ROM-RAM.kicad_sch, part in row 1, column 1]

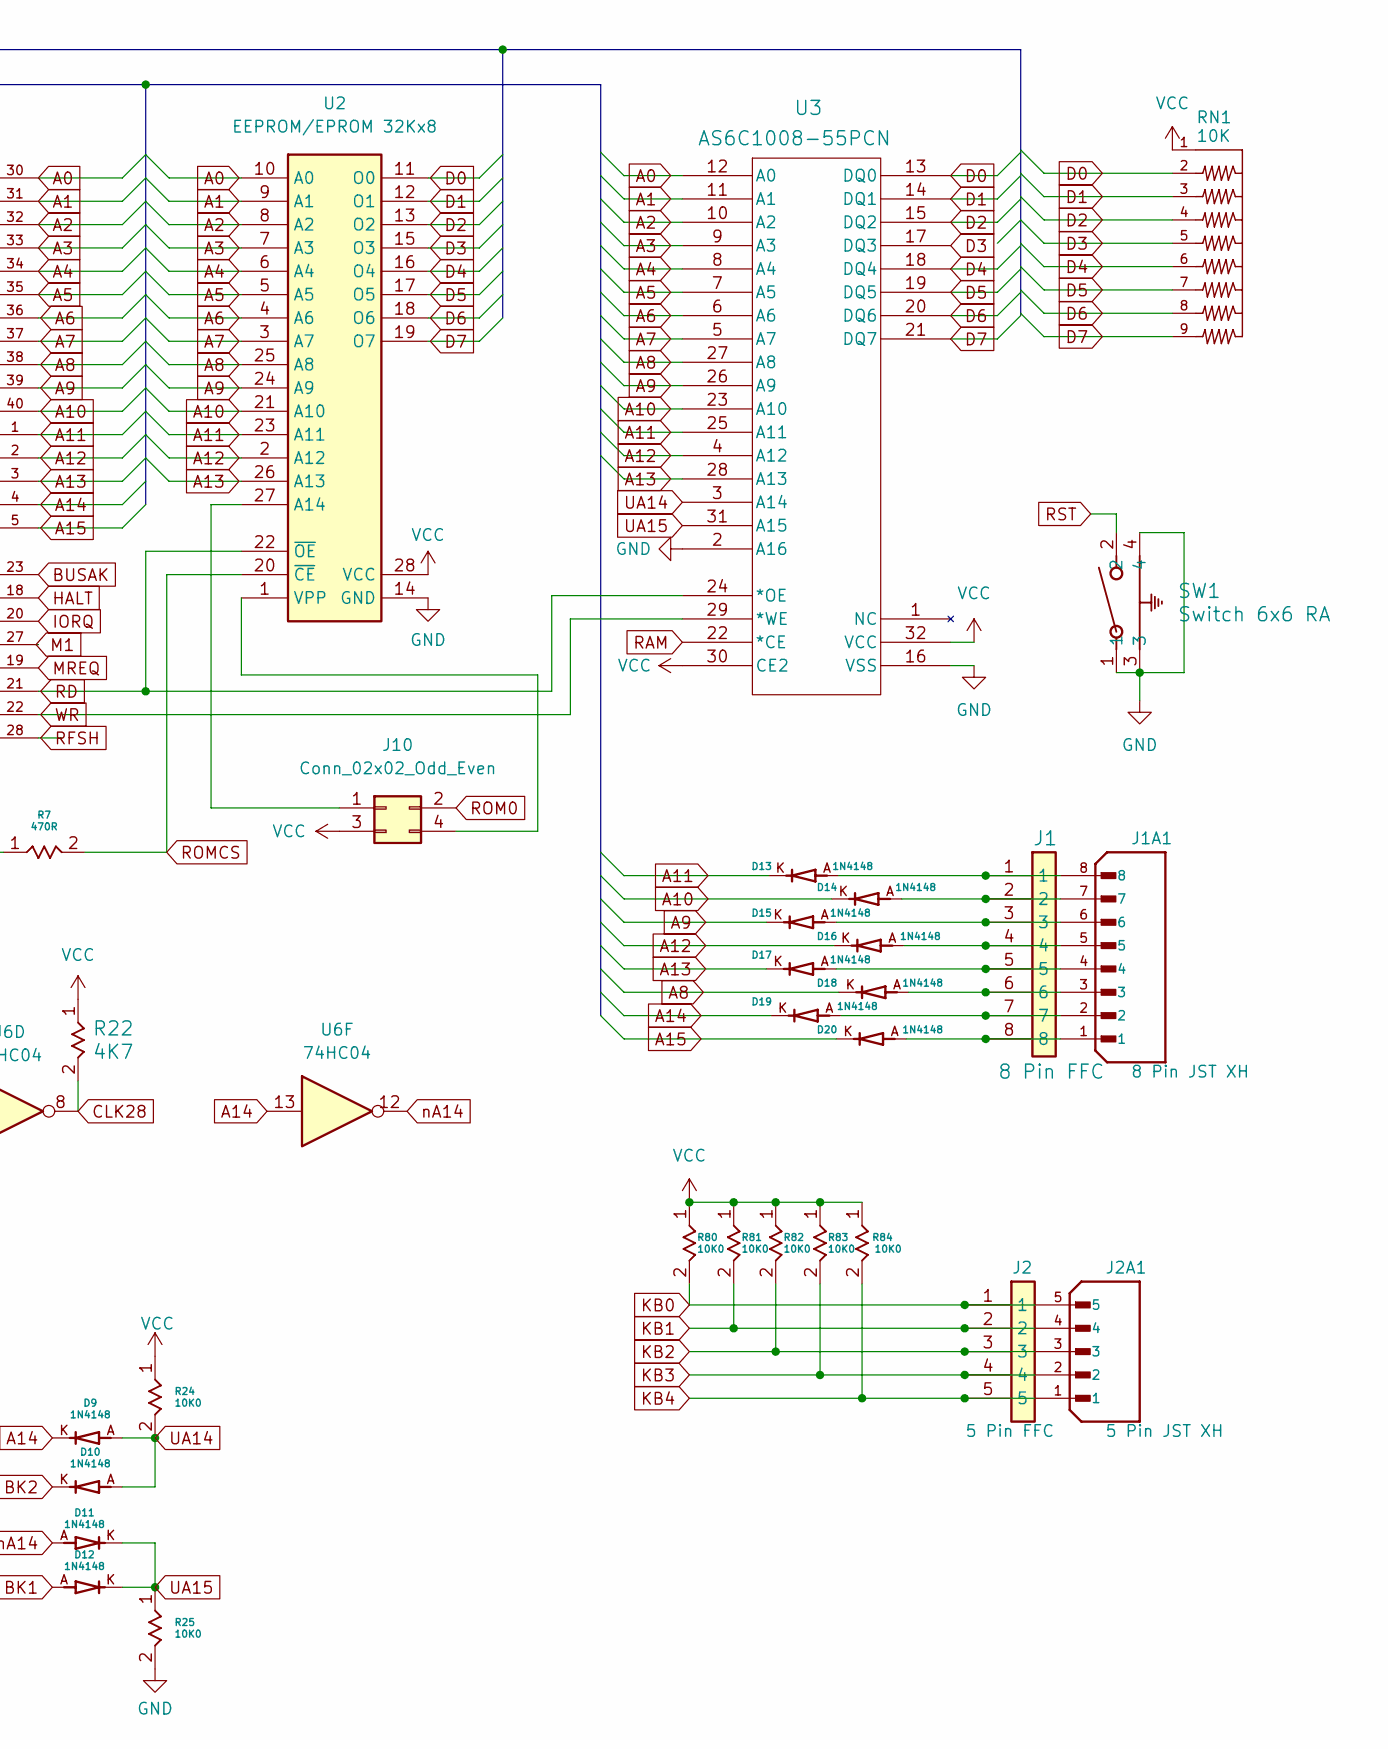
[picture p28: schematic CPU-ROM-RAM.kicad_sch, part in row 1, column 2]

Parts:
C1: 10uF 25V; CAPPRD200W50D500H1100; Mouser Part Number 667-ECA-1EM100B
C6, C7: 27pF; CAPRB250W50L400T250H550; PARTREV 20200310
D1, D9, D10, D11, D12, D13, D14, D15, D16, D17, D18, D19, D20: 1N4148; DIOAD753W49L380D172B; PARTREV 5
J1: 8 Pin FFC; 55203155
J1A1: 8 Pin JST XH; JST_B8B-XH-A_LF__SN_; PARTREV 7/4/21
J2: 5 Pin FFC; 55203155; Mouser Part Number 571-5-520315-5
J2A1: 5 Pin JST XH; JST_B5B-XH-A_LF__SN_; PARTREV 7/4/21
J10: Conn_02x02_Odd_Even; PinHeader_2x02_P2.54mm_Vertical
R3, R4, R5, R6, R24, R25, R80, R81, R82, R83, R84: 10K0; STA_CF14_STP
R7, R12, R32, R58, R59, R60, R61, R62, R63, R64, R65, R66, R67, R68, R69, R70, R71, R72, R73, R74, R75, R76, R77, R78, R79: 470R; STA_CF14_STP
R10: 1M00; STA_CF14_STP
R11: 1K00; STA_CF14_STP
R17, R22: 4K7; STA_CF14_STP
RN1: 10K; SIP249W50P254L2281H508Q9; PARTREV 10/1/20
SW1: Switch 6x6 RA; SW2_1825027-G_TEC
U1: Z80; Z80_Socket
U2: EEPROM/EPROM 32Kx8; DIP1556W56P254L3702H483Q28N; Mouser Part Number 556-AT27C256R-45PU
U3: AS6C1008-55PCN; U3
U4: AS6C1008-55PCN; PDIP-32_MIL600_ALL
U6: 74HC04; DIP794W53P254L1930H508Q14N
U9: SN74HC174N; DIP794W53P254L1930H508Q16N; Mouser Part Number 595-SN74HC174N
Y1: 28.375Mhz; Crystal_HC49-4H_Vertical

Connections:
A0: R79.2, U1.30 (A0), U2.10 (A0), U3.12 (A0); also elsewhere on the board
A1: R78.2, U1.31 (A1), U2.9 (A1), U3.11 (A1); also elsewhere on the board
A2: R77.2, U1.32 (A2), U2.8 (A2), U3.10 (A2); also elsewhere on the board
A3: R76.2, U1.33 (A3), U2.7 (A3), U3.9 (A3); also elsewhere on the board
A4: R75.2, U1.34 (A4), U2.6 (A4), U3.8 (A4); also elsewhere on the board
A5: R74.2, U1.35 (A5), U2.5 (A5), U3.7 (A5); also elsewhere on the board
A6: R73.2, U1.36 (A6), U2.4 (A6), U3.6 (A6); also elsewhere on the board
A7: R72.2, U1.37 (A7), U2.3 (A7), U3.5 (A7); also elsewhere on the board
A8: D18.K, R66.2, U1.38 (A8), U2.25 (A8), U3.27 (A8); also elsewhere on the board
A9: D15.K, R67.2, U1.39 (A9), U2.24 (A9), U3.26 (A9); also elsewhere on the board
A10: D14.K, R68.2, U1.40 (A10), U2.21 (A10), U3.23 (A10); also elsewhere on the board
A11: D13.K, R69.2, U1.1 (A11), U2.23 (A11), U3.25 (A11); also elsewhere on the board
A12: D16.K, R70.2, U1.2 (A12), U2.2 (A12), U3.4 (A12); also elsewhere on the board
A13: D17.K, R71.2, U1.3 (A13), U2.26 (A13), U3.28 (A13); also elsewhere on the board
A14: D9.K, D19.K, U1.4 (A14), U6.13; also elsewhere on the board
A15: D20.K, U1.5 (A15); also elsewhere on the board
BANK: R12.1; also elsewhere on the board
BK0: U9.2 (1Q); also elsewhere on the board
BK1: D12.A, U9.5 (2Q); also elsewhere on the board
BK2: D10.K, U9.7 (3Q); also elsewhere on the board
BUSAK: U1.23 (~BUSACK); also elsewhere on the board
BUSRQ: R5.2, U1.25 (~BUSREQ); also elsewhere on the board
CLK: R17.2, U1.6 (CLK); also elsewhere on the board
CLK28: R22.2, U6.8; also elsewhere on the board
D0: R58.2, RN1.2, U1.14 (D0), U2.11 (O0), U3.13 (DQ0), U9.3 (1D); also elsewhere on the board
D1: R59.2, RN1.3, U1.15 (D1), U2.12 (O1), U3.14 (DQ1), U9.4 (2D); also elsewhere on the board
D2: R60.2, RN1.4, U1.12 (D2), U2.13 (O2), U3.15 (DQ2), U9.6 (3D); also elsewhere on the board
D3: R61.2, RN1.5, U1.8 (D3), U2.15 (O3), U3.17 (DQ3), U9.11 (4D); also elsewhere on the board
D4: R62.2, RN1.6, U1.7 (D4), U2.16 (O4), U3.18 (DQ4), U9.13 (5D); also elsewhere on the board
D5: R63.2, RN1.7, U1.9 (D5), U2.17 (O5), U3.19 (DQ5), U9.14 (6D); also elsewhere on the board
D6: R64.2, RN1.8, U1.10 (D6), U2.18 (O6), U3.20 (DQ6); also elsewhere on the board
D7: R65.2, RN1.9, U1.13 (D7), U2.19 (O7), U3.21 (DQ7); also elsewhere on the board
GND: C1.2 (-), C6.2, C7.2, R25.2, SW1.1, SW1.3, SW1.4, U1.29 (GND), U2.14 (GND), U3.2 (A16), U3.16 (VSS), U4.16 (VSS), U6.1, U6.7 (GND), U9.8 (GND); also elsewhere on the board
HALT: U1.18 (~HALT); also elsewhere on the board
INT: R32.2, U1.16 (~INT); also elsewhere on the board
INTx: R32.1; also elsewhere on the board
IORQ: U1.20 (~IORQ); also elsewhere on the board
KB0: J2.1, J2A1.5, R80.2; also elsewhere on the board
KB1: J2.2, J2A1.4, R81.2; also elsewhere on the board
KB2: J2.3, J2A1.3, R82.2; also elsewhere on the board
KB3: J2.4, J2A1.2, R83.2; also elsewhere on the board
KB4: J2.5, J2A1.1, R84.2; also elsewhere on the board
M1: U1.27 (~M1); also elsewhere on the board
MREQ: U1.19 (~MREQ); also elsewhere on the board
NMI: R3.2, U1.17 (~NMI); also elsewhere on the board
unnamed: C6.1, R10.1, U6.5, Y1.1
unnamed: C7.1, R11.2, Y1.2
unnamed: D13.A, J1.1, J1A1.8
unnamed: D14.A, J1.2, J1A1.7
unnamed: D15.A, J1.3, J1A1.6
unnamed: D16.A, J1.4, J1A1.5
unnamed: D17.A, J1.5, J1A1.4
unnamed: D18.A, J1.6, J1A1.3
unnamed: D19.A, J1.7, J1A1.2
unnamed: D20.A, J1.8, J1A1.1
unnamed: J10.1, U2.27 (A14)
unnamed: J10.4, U2.1 (VPP)
unnamed: R10.2, R11.1, U6.6, U6.9
unnamed: U6.2, U6.3
unnamed: U6.4, U6.11
unnamed: D1.A, U9.15 (6Q)
unnamed: D1.K, R12.2, U9.9 (CLK)
RAM: U3.22 (*CE); also elsewhere on the board
RD: U1.21 (~RD), U2.22 (~OE), U3.24 (*OE); also elsewhere on the board
RFSH: U1.28 (~RFSH); also elsewhere on the board
ROM: R7.1; also elsewhere on the board
ROM0: J10.2, U9.12 (5Q)
ROMCS: R7.2, U2.20 (~CE); also elsewhere on the board
RST: C1.1 (+), R6.2, SW1.2, U1.26 (~RESET), U9.1 (~CLR); also elsewhere on the board
UA14: D9.A, D10.A, R24.2, U3.3 (A14)
UA15: D11.K, D12.K, R25.1, U3.31 (A15)
VA0: R79.1, U4.12 (A0); also elsewhere on the board
VA1: R78.1, U4.11 (A1); also elsewhere on the board
VA2: R77.1, U4.10 (A2); also elsewhere on the board
VA3: R76.1, U4.9 (A3); also elsewhere on the board
VA4: R75.1, U4.8 (A4); also elsewhere on the board
VA5: R74.1, U4.7 (A5); also elsewhere on the board
VA6: R73.1, U4.6 (A6); also elsewhere on the board
VA7: R72.1, U4.5 (A7); also elsewhere on the board
VA8: R66.1, U4.27 (A8); also elsewhere on the board
VA9: R67.1, U4.26 (A9); also elsewhere on the board
VA10: R68.1, U4.23 (A10); also elsewhere on the board
VA11: R69.1, U4.25 (A11); also elsewhere on the board
VA12: R70.1, U4.4 (A12); also elsewhere on the board
VA13: R71.1, U4.28 (A13); also elsewhere on the board
VA14: U4.3 (A14); also elsewhere on the board
VA15: U4.2 (A16); also elsewhere on the board
VB: U9.10 (4Q); also elsewhere on the board
VCC: J10.3, R3.1, R4.1, R5.1, R6.1, R17.1, R22.1, R24.1, R80.1, R81.1, R82.1, R83.1, R84.1, RN1.1, U1.11 (+5V), U2.28 (VCC), U3.30 (CE2), U3.32 (VCC), U4.30 (CE2), U4.31 (A15), U4.32 (VCC), U6.14 (VCC), U9.16 (VCC); also elsewhere on the board
VCS: U4.22 (*CE); also elsewhere on the board
VD0: R58.1, U4.13 (DQ0); also elsewhere on the board
VD1: R59.1, U4.14 (DQ1); also elsewhere on the board
VD2: R60.1, U4.15 (DQ2); also elsewhere on the board
VD3: R61.1, U4.17 (DQ3); also elsewhere on the board
VD4: R62.1, U4.18 (DQ4); also elsewhere on the board
VD5: R63.1, U4.19 (DQ5); also elsewhere on the board
VD6: R64.1, U4.20 (DQ6); also elsewhere on the board
VD7: R65.1, U4.21 (DQ7); also elsewhere on the board
VRD: U4.24 (*OE); also elsewhere on the board
VWR: U4.29 (*WE); also elsewhere on the board
WAIT: R4.2, U1.24 (~WAIT); also elsewhere on the board
WR: U1.22 (~WR), U3.29 (*WE); also elsewhere on the board
nA14: D11.A, U6.12

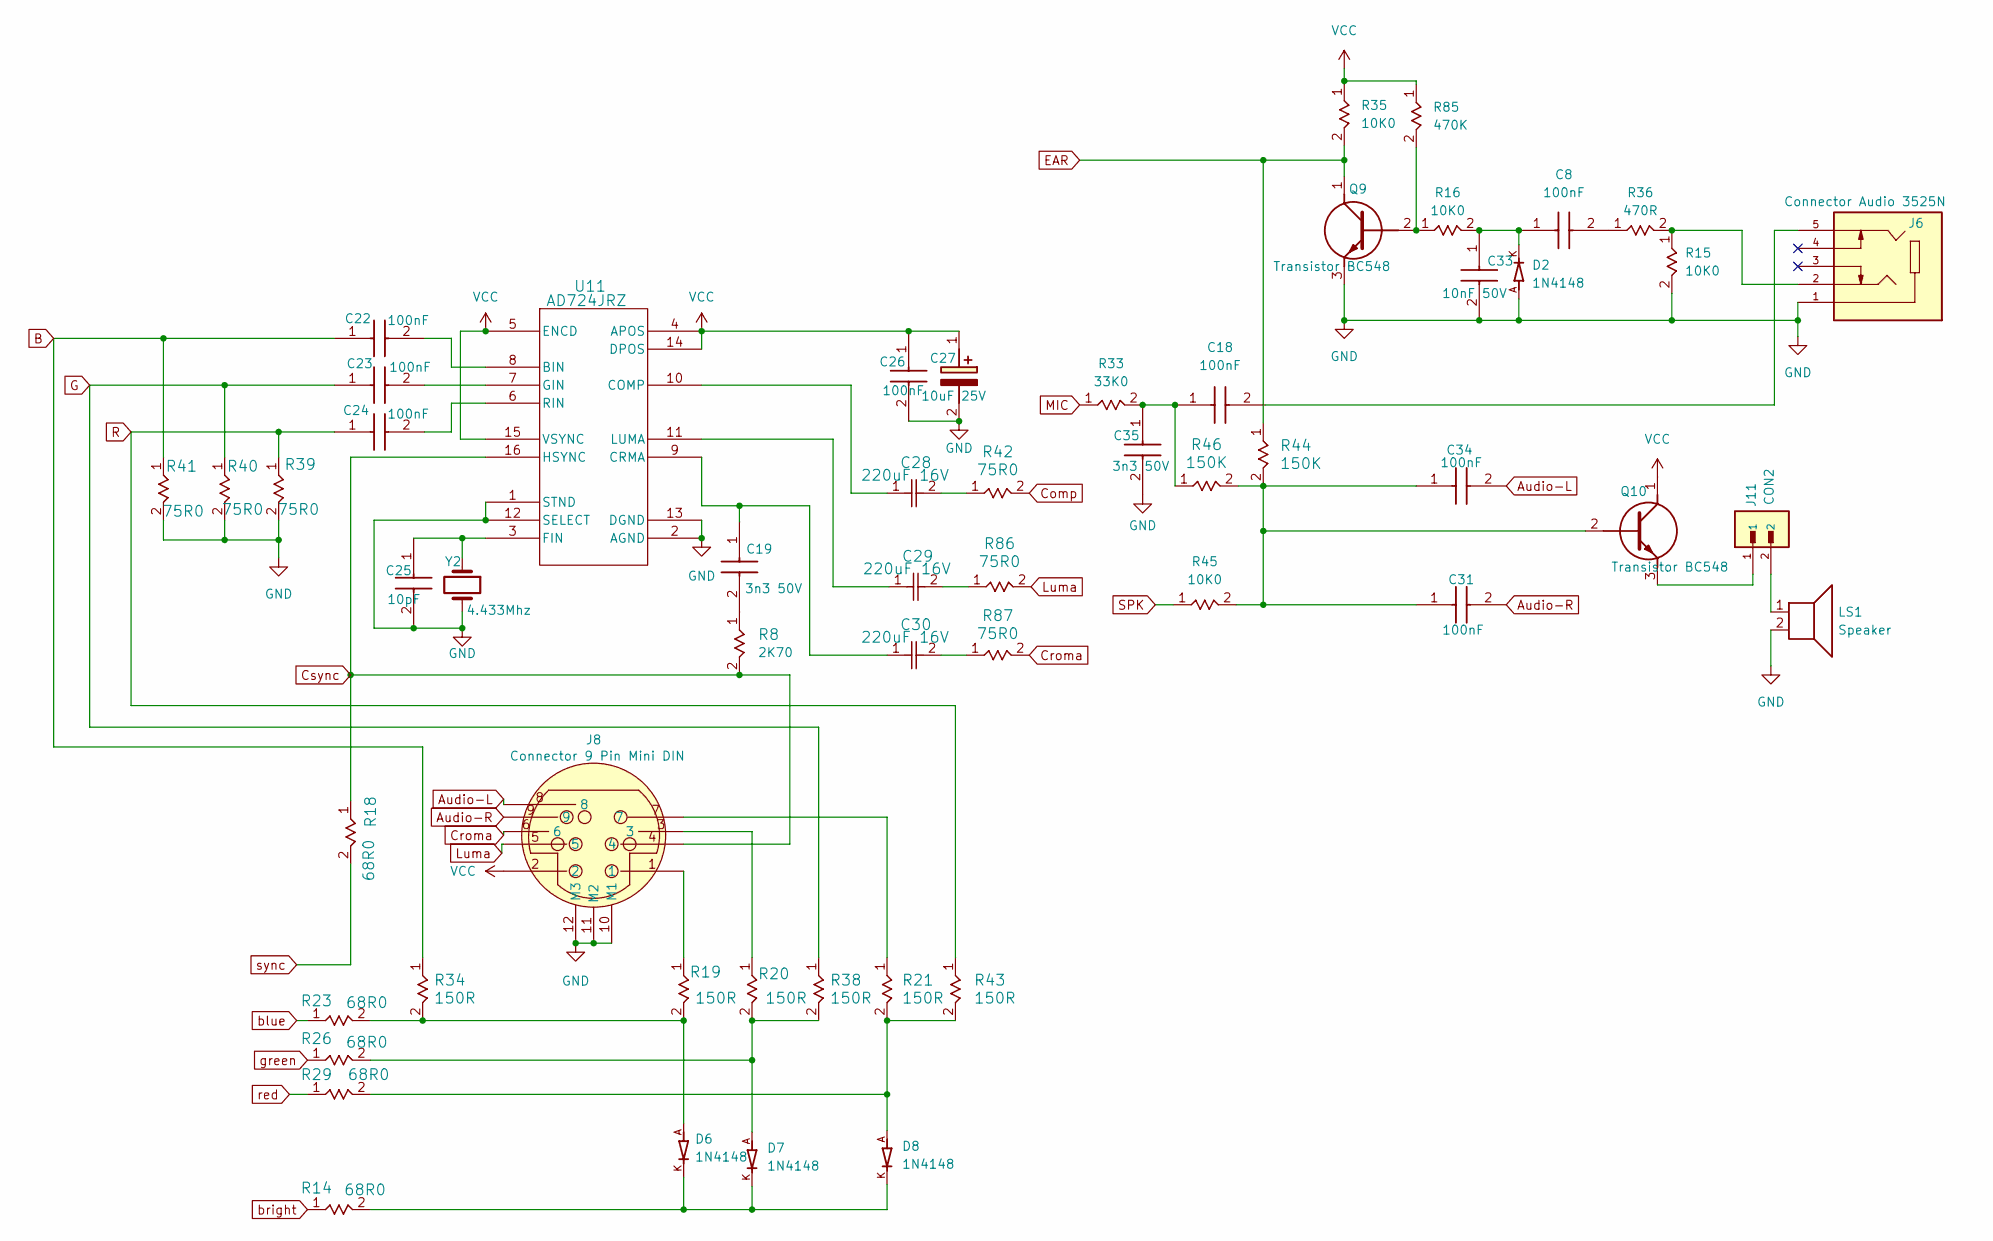
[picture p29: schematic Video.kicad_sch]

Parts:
C8, C18, C22, C23, C24, C26, C31, C34: 100nF; CAPRB250W50L400T250H550; Mouser Part Number 594-K104Z15Y5VF5TL2
C19, C35: 3n3 50V; CAPRB250W50L400T250H550; Mouser Part Number 594-K104Z15Y5VF5TL2
C25: 10pF; CAPRB250W50L400T250H550; Mouser Part Number 594-K104Z15Y5VF5TL2
C27: 10uF 25V; CAPPRD200W50D500H1100; Mouser Part Number 667-ECA-1EM100B
C28, C29, C30: 220uF 16V; CAP_YX_6P3X11_RUB
C33: 10nF 50V; CAPRB250W50L400T250H550; Mouser Part Number 594-K104Z15Y5VF5TL2
D2, D6, D7, D8: 1N4148; DIOAD753W49L380D172B; PARTREV 5
J6: Connector Audio 3525N; CUI_SJ1-3525N
J8: Connector 9 Pin Mini DIN; KMDGX9SBS1
J11: CON2; HARWIN_M20-9990246; PARTREV 14
LS1: Speaker
Q9, Q10: Transistor BC548; BC548BTA
R8: 2K70; STA_CF14_STP
R14, R18, R23, R26, R29: 68R0; STA_CF14_STP
R15, R16, R35, R45: 10K0; STA_CF14_STP
R19, R20, R21, R34, R38, R43: 150R; STA_CF14_STP
R33: 33K0; STA_CF14_STP
R36: 470R; STA_CF14_STP
R39, R40, R41, R42, R86, R87: 75R0; STA_CF14_STP
R44, R46: 150K; STA_CF14_STP
R85: 470K; STA_CF14_STP
U11: AD724JRZ; RW_16_ADI
Y2: 4.433Mhz; Crystal_HC49-4H_Vertical

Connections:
Audio-L: C34.2 (-), J8.8; also elsewhere on the board
Audio-R: C31.2 (-), J8.9; also elsewhere on the board
B: C22.1 (+), R34.1, R41.1
Comp: R42.2; also elsewhere on the board
Croma: J8.6, R87.2
Csync: J8.4, R8.2, R18.1, U11.16 (HSYNC)
EAR: Q9.1 (C), R35.2, R44.1; also elsewhere on the board
G: C23.1 (+), R38.1, R40.1
GND: C25.2 (-), C26.2 (-), C27.2 (-), C33.2 (-), C35.2 (-), D2.A, J6.1, J8.10 (M1), J8.11 (M2), J8.12 (M3), LS1.2, Q9.3 (E), R15.2, R39.2, R40.2, R41.2, U11.1 (STND), U11.2 (AGND), U11.12 (SELECT), U11.13 (DGND), Y2.2; also elsewhere on the board
Luma: J8.5, R86.2
MIC: R33.1; also elsewhere on the board
unnamed: C8.2 (-), R36.1
unnamed: C18.1 (+), C35.1 (+), R33.2, R46.1
unnamed: C18.2 (-), J6.5
unnamed: C19.1 (+), C30.1, U11.9 (CRMA)
unnamed: C19.2 (-), R8.1
unnamed: C22.2 (-), U11.8 (BIN)
unnamed: C23.2 (-), U11.7 (GIN)
unnamed: C24.2 (-), U11.6 (RIN)
unnamed: C25.1 (+), U11.3 (FIN), Y2.1
unnamed: C28.2, R42.1
unnamed: C29.2, R86.1
unnamed: C30.2, R87.1
unnamed: C31.1 (+), C34.1 (+), Q10.2 (B), R44.2, R45.2, R46.2
unnamed: C8.1 (+), C33.1 (+), D2.K, R16.2
unnamed: D6.A, R19.2, R23.2, R34.2
unnamed: D6.K, D7.K, D8.K, R14.2
unnamed: D7.A, R20.2, R26.2, R38.2
unnamed: D8.A, R21.2, R29.2, R43.2
unnamed: J6.2, R15.1, R36.2
unnamed: J8.1, R19.1
unnamed: J8.3, R20.1
unnamed: J8.7, R21.1
unnamed: J11.2, LS1.1
unnamed: Q9.2 (B), R16.1, R85.2
unnamed: J11.1, Q10.3 (E)
unnamed: C28.1, U11.10 (COMP)
unnamed: C29.1, U11.11 (LUMA)
R: C24.1 (+), R39.1, R43.1
SPK: R45.1; also elsewhere on the board
VCC: C26.1 (+), C27.1 (+), J8.2, Q10.1 (C), R35.1, R85.1, U11.4 (APOS), U11.5 (ENCD), U11.14 (DPOS), U11.15 (VSYNC); also elsewhere on the board
blue: R23.1; also elsewhere on the board
bright: R14.1; also elsewhere on the board
green: R26.1; also elsewhere on the board
red: R29.1; also elsewhere on the board
sync: R18.2; also elsewhere on the board

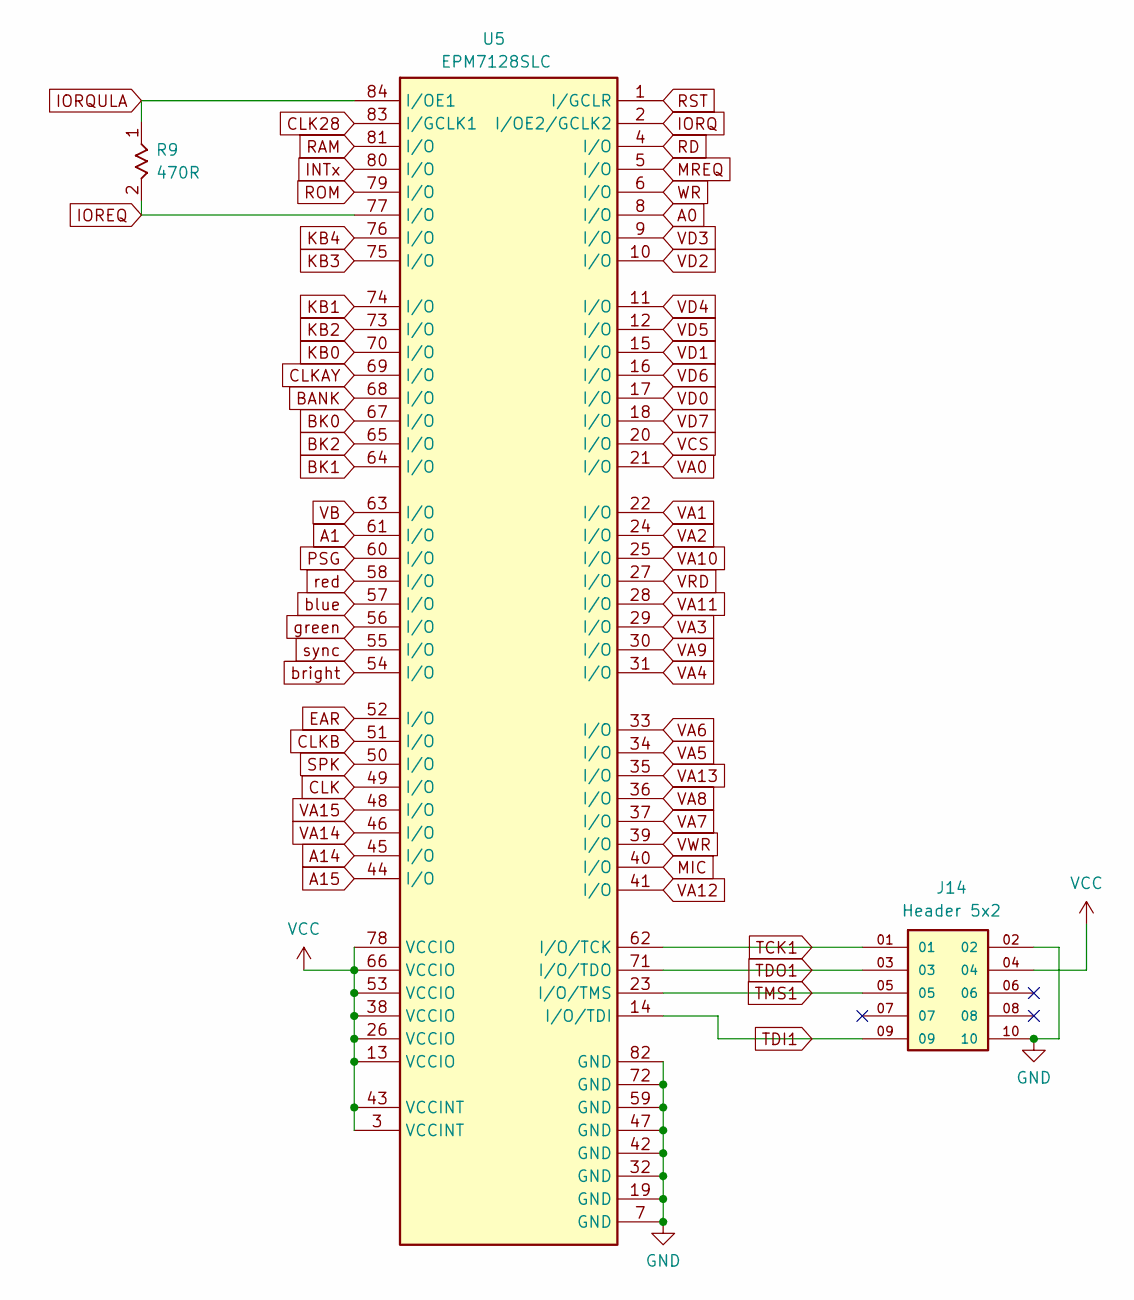
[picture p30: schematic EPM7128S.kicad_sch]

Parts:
J14: Header 5x2; AMPHENOL_10129381-910002BLF; PARTREV D
R9: 470R; STA_CF14_STP
U5: EPM7128SLC; PLCC84AT

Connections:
A0: U5.8 (I/O); also elsewhere on the board
A1: U5.61 (I/O); also elsewhere on the board
A14: U5.45 (I/O); also elsewhere on the board
A15: U5.44 (I/O); also elsewhere on the board
BANK: U5.68 (I/O); also elsewhere on the board
BK0: U5.67 (I/O); also elsewhere on the board
BK1: U5.64 (I/O); also elsewhere on the board
BK2: U5.65 (I/O); also elsewhere on the board
CLK: U5.49 (I/O); also elsewhere on the board
CLK28: U5.83 (I/GCLK1); also elsewhere on the board
CLKAY: U5.69 (I/O); also elsewhere on the board
CLKB: U5.51 (I/O); also elsewhere on the board
EAR: U5.52 (I/O); also elsewhere on the board
GND: J14.02, J14.10, U5.7 (GND), U5.19 (GND), U5.32 (GND), U5.42 (GND), U5.47 (GND), U5.59 (GND), U5.72 (GND), U5.82 (GND); also elsewhere on the board
INTx: U5.80 (I/O); also elsewhere on the board
IOREQ: R9.2, U5.77 (I/O)
IORQ: U5.2 (I/OE2/GCLK2); also elsewhere on the board
IORQULA: R9.1, U5.84 (I/OE1); also elsewhere on the board
KB0: U5.70 (I/O); also elsewhere on the board
KB1: U5.74 (I/O); also elsewhere on the board
KB2: U5.73 (I/O); also elsewhere on the board
KB3: U5.75 (I/O); also elsewhere on the board
KB4: U5.76 (I/O); also elsewhere on the board
MIC: U5.40 (I/O); also elsewhere on the board
MREQ: U5.5 (I/O); also elsewhere on the board
PSG: U5.60 (I/O); also elsewhere on the board
RAM: U5.81 (I/O); also elsewhere on the board
RD: U5.4 (I/O); also elsewhere on the board
ROM: U5.79 (I/O); also elsewhere on the board
RST: U5.1 (I/GCLR); also elsewhere on the board
SPK: U5.50 (I/O); also elsewhere on the board
TCK1: J14.01, U5.62 (I/O/TCK)
TDI1: J14.09, U5.14 (I/O/TDI)
TDO1: J14.03, U5.71 (I/O/TDO)
TMS1: J14.05, U5.23 (I/O/TMS)
VA0: U5.21 (I/O); also elsewhere on the board
VA1: U5.22 (I/O); also elsewhere on the board
VA2: U5.24 (I/O); also elsewhere on the board
VA3: U5.29 (I/O); also elsewhere on the board
VA4: U5.31 (I/O); also elsewhere on the board
VA5: U5.34 (I/O); also elsewhere on the board
VA6: U5.33 (I/O); also elsewhere on the board
VA7: U5.37 (I/O); also elsewhere on the board
VA8: U5.36 (I/O); also elsewhere on the board
VA9: U5.30 (I/O); also elsewhere on the board
VA10: U5.25 (I/O); also elsewhere on the board
VA11: U5.28 (I/O); also elsewhere on the board
VA12: U5.41 (I/O); also elsewhere on the board
VA13: U5.35 (I/O); also elsewhere on the board
VA14: U5.46 (I/O); also elsewhere on the board
VA15: U5.48 (I/O); also elsewhere on the board
VB: U5.63 (I/O); also elsewhere on the board
VCC: J14.04, U5.3 (VCCINT), U5.13 (VCCIO), U5.26 (VCCIO), U5.38 (VCCIO), U5.43 (VCCINT), U5.53 (VCCIO), U5.66 (VCCIO), U5.78 (VCCIO); also elsewhere on the board
VCS: U5.20 (I/O); also elsewhere on the board
VD0: U5.17 (I/O); also elsewhere on the board
VD1: U5.15 (I/O); also elsewhere on the board
VD2: U5.10 (I/O); also elsewhere on the board
VD3: U5.9 (I/O); also elsewhere on the board
VD4: U5.11 (I/O); also elsewhere on the board
VD5: U5.12 (I/O); also elsewhere on the board
VD6: U5.16 (I/O); also elsewhere on the board
VD7: U5.18 (I/O); also elsewhere on the board
VRD: U5.27 (I/O); also elsewhere on the board
VWR: U5.39 (I/O); also elsewhere on the board
WR: U5.6 (I/O); also elsewhere on the board
blue: U5.57 (I/O); also elsewhere on the board
bright: U5.54 (I/O); also elsewhere on the board
green: U5.56 (I/O); also elsewhere on the board
red: U5.58 (I/O); also elsewhere on the board
sync: U5.55 (I/O); also elsewhere on the board

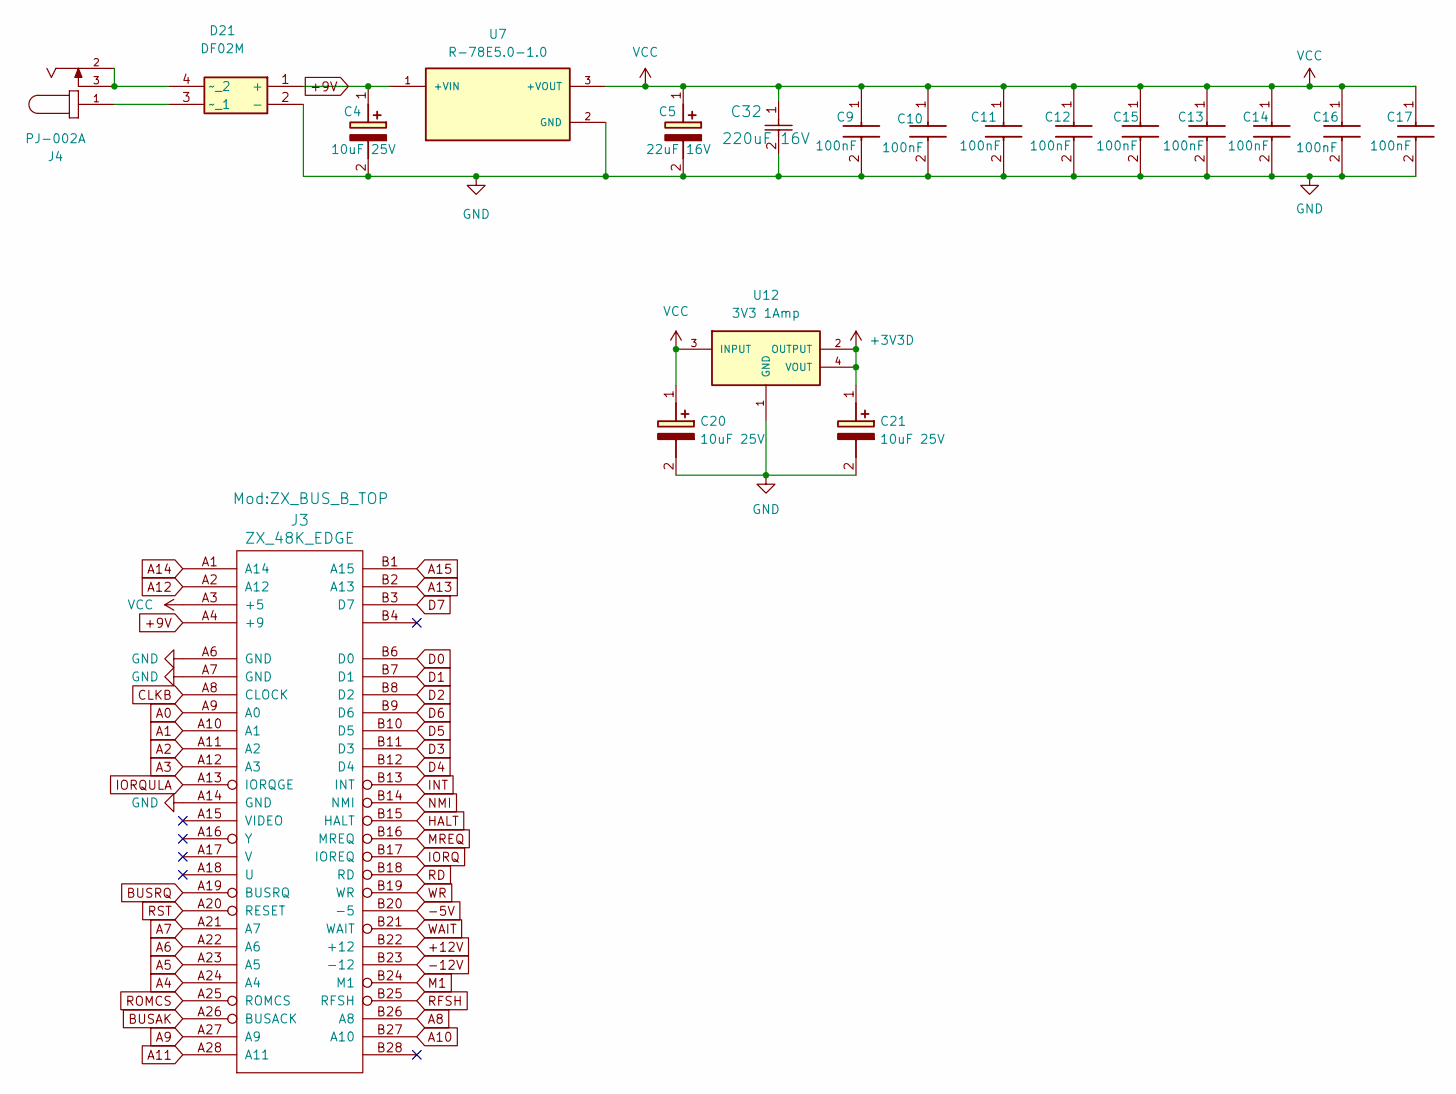
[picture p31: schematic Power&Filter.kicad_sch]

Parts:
C4, C20, C21: 10uF 25V; CAPPRD200W50D500H1100; Mouser Part Number 667-ECA-1EM100B
C5: 22uF 16V; CAPPRD200W50D500H1100; Mouser Part Number 667-ECA-1EM100B
C9, C10, C11, C12, C13, C14, C16, C17: 100nF; CAPRB250W50L400T250H550; Mouser Part Number 594-K104Z15Y5VF5TL2
C15: 100nF; Capacitor 3.8mm PItch; Mouser Part Number 594-K104Z15Y5VF5TL2
C32: 220uF 16V; CAP_YX_6P3X11_RUB
D21: DF02M; DIP825W58P510L832H543Q4N; Mouser Part Number 621-DF02M
J3: ZX_48K_EDGE; ZX_BUS_B_TOP
J4: PJ-002A; CUI_PJ-002A
U7: R-78E5.0-1.0; CONV_R-78E5.0-1.0; PARTREV 6
U12: 3V3 1Amp; SOT230P700X185-4N

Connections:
+3V3D: C21.1 (+), U12.2 (OUTPUT), U12.4 (VOUT); also elsewhere on the board
+9V: C4.1 (+), D21.1 (+), J3.A4 (+9), U7.1 (+VIN)
+12V: J3.B22 (+12)
-5V: J3.B20 (-5)
-12V: J3.B23 (-12)
A0: J3.A9 (A0); also elsewhere on the board
A1: J3.A10 (A1); also elsewhere on the board
A2: J3.A11 (A2); also elsewhere on the board
A3: J3.A12 (A3); also elsewhere on the board
A4: J3.A24 (A4); also elsewhere on the board
A5: J3.A23 (A5); also elsewhere on the board
A6: J3.A22 (A6); also elsewhere on the board
A7: J3.A21 (A7); also elsewhere on the board
A8: J3.B26 (A8); also elsewhere on the board
A9: J3.A27 (A9); also elsewhere on the board
A10: J3.B27 (A10); also elsewhere on the board
A11: J3.A28 (A11); also elsewhere on the board
A12: J3.A2 (A12); also elsewhere on the board
A13: J3.B2 (A13); also elsewhere on the board
A14: J3.A1 (A14); also elsewhere on the board
A15: J3.B1 (A15); also elsewhere on the board
BUSAK: J3.A26 (BUSACK); also elsewhere on the board
BUSRQ: J3.A19 (BUSRQ); also elsewhere on the board
CLKB: J3.A8 (CLOCK); also elsewhere on the board
D0: J3.B6 (D0); also elsewhere on the board
D1: J3.B7 (D1); also elsewhere on the board
D2: J3.B8 (D2); also elsewhere on the board
D3: J3.B11 (D3); also elsewhere on the board
D4: J3.B12 (D4); also elsewhere on the board
D5: J3.B10 (D5); also elsewhere on the board
D6: J3.B9 (D6); also elsewhere on the board
D7: J3.B3 (D7); also elsewhere on the board
GND: C4.2 (-), C5.2 (-), C9.2 (-), C10.2 (-), C11.2 (-), C12.2 (-), C13.2 (-), C14.2 (-), C15.2 (-), C16.2 (-), C17.2 (-), C20.2 (-), C21.2 (-), C32.2, D21.2 (-), J3.A6 (GND), J3.A7 (GND), J3.A14 (GND), U7.2 (GND), U12.1 (GND); also elsewhere on the board
HALT: J3.B15 (HALT); also elsewhere on the board
INT: J3.B13 (INT); also elsewhere on the board
IORQ: J3.B17 (IOREQ); also elsewhere on the board
IORQULA: J3.A13 (IORQGE); also elsewhere on the board
M1: J3.B24 (M1); also elsewhere on the board
MREQ: J3.B16 (MREQ); also elsewhere on the board
NMI: J3.B14 (NMI); also elsewhere on the board
unnamed: D21.3 (~_1), J4.1
unnamed: D21.4 (~_2), J4.2, J4.3
RD: J3.B18 (RD); also elsewhere on the board
RFSH: J3.B25 (RFSH); also elsewhere on the board
ROMCS: J3.A25 (ROMCS); also elsewhere on the board
RST: J3.A20 (RESET); also elsewhere on the board
VCC: C5.1 (+), C9.1 (+), C10.1 (+), C11.1 (+), C12.1 (+), C13.1 (+), C14.1 (+), C15.1 (+), C16.1 (+), C17.1 (+), C20.1 (+), C32.1, J3.A3 (+5), U7.3 (+VOUT), U12.3 (INPUT); also elsewhere on the board
WAIT: J3.B21 (WAIT); also elsewhere on the board
WR: J3.B19 (WR); also elsewhere on the board

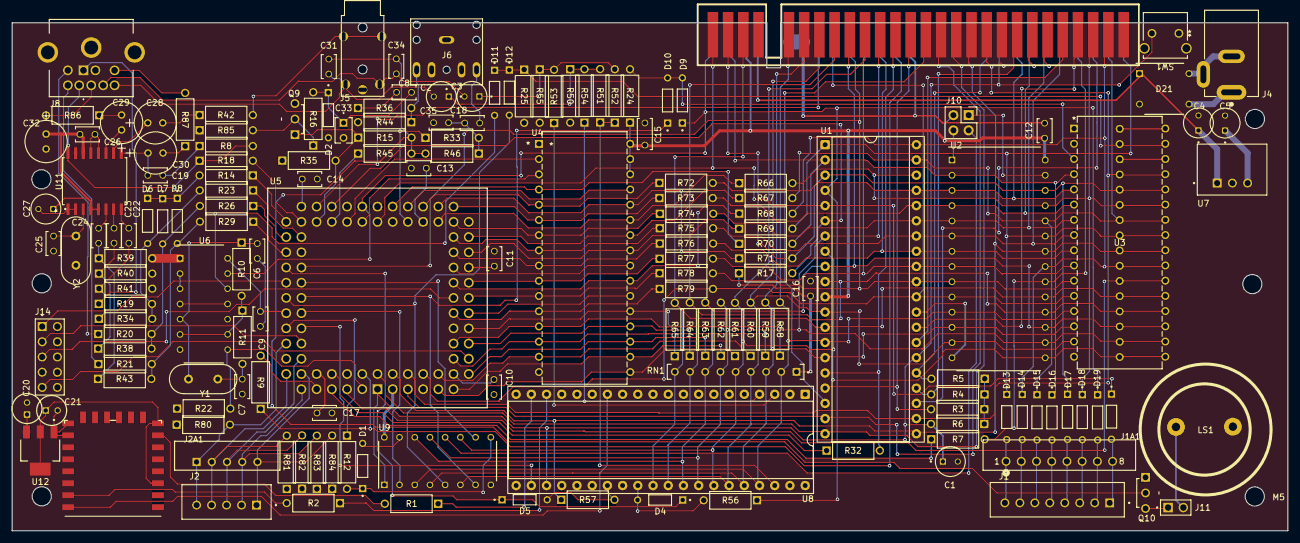
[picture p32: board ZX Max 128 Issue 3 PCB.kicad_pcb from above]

Board: 2 copper layers, 213.0 x 84.8 mm, 170 parts (0 on the bottom side), 172 nets.

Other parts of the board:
C2, C3: 10uF 25V; CAPPRD200W50D500H1100
D4, D5: 1N4148; DIOAD753W49L380D172B
J5: AV Jack; PJ-322A
R1, R2, R56, R57: 470R; STA_CF14_STP
R50, R53, R54, R55: 1K00; STA_CF14_STP
R51, R52: 2K20; STA_CF14_STP
U8: AY-3-8910; Z80_Socket
U15: ESP8266-12E; WIFI_Module_ESP8266_12E

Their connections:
+3V3D: U15.3 (EN), U15.8 (VCC); also elsewhere on the board
/Turbo Sound/L-in: C3.1 (+), R52.2, R53.2, R55.1
/Turbo Sound/R-in: C2.1 (+), R50.2, R51.2, R54.1
A14: R56.1; also elsewhere on the board
A-AY: R50.1, U8.4 (CHANNEL_A)
Audio-L: C3.2 (-), J5.2; also elsewhere on the board
Audio-R: C2.2 (-), J5.4; also elsewhere on the board
B-AY: R53.1, U8.3 (CHANNEL_B)
BC1: D4.A, R56.2, U8.29 (BC1)
BDIR: D5.A, R57.2, U8.27 (BDIR)
C-AY: R51.1, R52.1, U8.38 (CHANNEL_C)
CLKAY: U8.22 (CLK); also elsewhere on the board
Comp: J5.3; also elsewhere on the board
D0: U8.37 (DA0); also elsewhere on the board
D1: U8.36 (DA1); also elsewhere on the board
D2: U8.35 (DA2); also elsewhere on the board
D3: U8.34 (DA3); also elsewhere on the board
D4: U8.33 (DA4); also elsewhere on the board
D5: U8.32 (DA5); also elsewhere on the board
D6: U8.31 (DA6); also elsewhere on the board
D7: U8.30 (DA7); also elsewhere on the board
GND: J5.1, R54.2, R55.2, U8.1 (VSS), U8.24 (~A9), U15.15 (GND), U15.16 (TXD2/IO15); also elsewhere on the board
IN4: U8.14 (IOA7), U15.22 (TXD0/TXD)
MIDI: R1.2, U15.7 (MOSI/IO13)
unnamed: R2.2, U15.21 (RXD0/RXD)
OUT3: R1.1, U8.19 (IOA2)
OUT4: R2.1, U8.18 (IOA3)
PSG: D4.K, D5.K; also elsewhere on the board
RD: R57.1; also elsewhere on the board
RST: U8.23 (~RESET); also elsewhere on the board
VCC: U8.25 (A8), U8.28 (BC2), U8.40 (VCC); also elsewhere on the board

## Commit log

2026-07-10 Add files via upload
    Initial Release
    [10129381-910002BLF.step, 16YXJ220MT16.3X11.step, 5-520315-5.stp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]
2026-07-10 Add files via upload
    Initial Upload
    [CPU-ROM-RAM.kicad_sch, EPM7128S.kicad_sch, Power&Filter.kicad_sch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]
2026-07-10 Revise README for ZX Max 128 project details
    Updated README to include additional details and corrections regarding the ZX Max 128 project, including jumper/connectors information and resistor recommendations.
2026-07-10 Revise README for accuracy and clarity
    Updated README to correct connector labels and clarify recommendations for component values.
2026-07-26 Revise README for clarity and accuracy
    Updated the README to clarify project details and assembly instructions, ensuring accuracy in component information and layout.

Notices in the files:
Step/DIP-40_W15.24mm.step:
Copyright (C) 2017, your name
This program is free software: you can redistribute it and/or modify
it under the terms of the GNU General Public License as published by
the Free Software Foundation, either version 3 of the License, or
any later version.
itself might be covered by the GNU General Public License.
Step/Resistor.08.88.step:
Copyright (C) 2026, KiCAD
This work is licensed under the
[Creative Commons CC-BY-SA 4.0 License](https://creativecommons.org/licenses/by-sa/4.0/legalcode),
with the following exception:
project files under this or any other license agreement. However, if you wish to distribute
